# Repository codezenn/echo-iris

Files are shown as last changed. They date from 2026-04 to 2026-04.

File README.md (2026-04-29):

# Echo IRIS

A voice interactive AI agent on a mini-Jeep platform. Built for ECE 202 at
Colorado State University, Spring 2026. This is the end-of-semester archive
of the Group 35 deliverable.

**Status.** v1.0.0 released April 22, 2026. Demo day shipped in Room C105/107.
This repository is the permanent home for the codebase, hardware
documentation, 3D models, and setup guides. Future ECE 202 teams are
encouraged to fork, extend, and pick up where Group 35 left off.

## What IRIS Stands For

Intelligent Raspberry-Pi Imaging System.

| Letter | Meaning |
|---|---|
| I | Intelligent  |
| R | Raspberry Pi |
| I | Imaging |
| S | System |

## What It Does

Walk up to the Jeep, say "hello IRIS," and ask a question. IRIS hears you
through a wireless lavalier mic, recognizes your speech locally with Vosk,
checks your question against a fast path keyword dictionary for common demo
questions, and either responds instantly or hands the question to a local
qwen3.5:2b language model running through Ollama. Piper text to speech
voices the answer through a USB sound card. Throughout the entire session,
a Sony IMX500 AI camera runs YOLO11n object detection on its on-camera
neural processor and shows visitors a live preview window with bounding
boxes drawn over themselves and surrounding objects. Ask "what do you see"
and IRIS uses the qwen3.5:2b vision model to describe the scene in spoken
English. Switch personalities by saying "switch to pirate mode" or "go
playful." Everything runs locally on the Pi with no cloud dependency.



## Team

| Member | Role |
|---|---|
| Marc S. | Project lead. AI agent, voice pipeline, software |
| Giovanni G. | 3D design and printing. Speaker mount, Pi enclosure |
| Obaid A. | Hardware. Jeep assembly, wiring, GPIO, power |

## Key Features

Wake word listening with conversation mode. After IRIS responds, the agent
stays in listening mode for 12 seconds so visitors can ask follow up
questions without resaying the wake word.

Local speech recognition via Vosk at 48 kHz. No internet required.

Local language model. qwen3.5:2b runs through Ollama on the Pi. The system
prompt and DEMO_ANSWERS keyword fast path handle approximately 80 percent
of expected demo day questions in under 100 milliseconds. The LLM handles
everything else.

Concurrent live object detection. YOLO11n runs continuously on the Sony
IMX500 on camera neural processor at zero Pi CPU cost. Visitors see
themselves highlighted with bounding boxes throughout the conversation.

On demand LLM vision. Ask "what do you see" and the qwen3.5:2b vision model
captures a frame and describes the scene in spoken English.

Three personality modes. Professional, playful, and pirate. Switch by voice
command at any time.

Conversation scoreboard. IRIS counts how many people it has talked to and
will tell you the count when asked.

Easter eggs. A few hidden surprises for the curious. Try asking what grade
the project deserves.

Chat memory. Conversation history persists across turns within a session
and is logged to disk for review.

Live status indicators. Discrete LEDs driven by an Arduino Nano R4 over
serial show wake/listen/think/speak/error states.

## Architecture at a Glance

```
arecord (48 kHz) -> Vosk -> [easter eggs / personality switch / scoreboard
                            / vision trigger / DEMO_ANSWERS / LLM]
                         -> Piper TTS -> pygame.mixer -> USB speaker

Sony IMX500 NPU -> YOLO11n -> Picamera2 -> live preview window (concurrent)

Voice trigger ("what do you see") -> rpicam-still -> qwen3.5:2b vision -> spoken response
```

For the full architecture writeup, see [docs/architecture.md](docs/architecture.md).

## Hardware Highlights

The full bill of materials with funding sources and unit costs lives in
[hardware/BOM.md](hardware/BOM.md). The headline components are below.

| Component | Notes |
|---|---|
| Raspberry Pi 5 (16GB) | Production board, NVMe boot |
| Sony IMX500 AI Camera | Runs YOLO11n on-camera at zero Pi CPU cost |
| Wireless K1 Lavalier Mic | 48 kHz USB Composite Device |
| Waveshare USB Sound Card | Speaker output, USB PnP Device |
| Arduino Nano R4 | LED status indicators, pan/tilt servos via PWM |
| UPS HAT B | Backup power, pogo pin connection (GPIO free)  |
| 512GB NVMe via M.2 HAT+  | Boot drive, primary storage |
| XGRAVITY Mini-Jeep | Cars4Kids "Gravity" platform, white variant |

For the chassis specifications and the spec source URL, see
[hardware/platform_specs.md](hardware/platform_specs.md).

## Software Stack

| Component | Tool |
|---|---|
| Speech recognition | Vosk (small English model, offline) |
| Language model | qwen3.5:2b via Ollama |
| Text to speech | Piper, en_GB-vctk-medium voice |
| Object detection | YOLO11n on Sony IMX500 NPU |
| Vision (on demand) | qwen3.5:2b vision via Ollama |
| Camera interface | Picamera2, rpicam-still |
| Audio playback | pygame.mixer |
| Microcontroller | Arduino Nano R4 (Renesas RA4M1) |
| Operating system | Raspberry Pi OS Bookworm 64-bit |
| Language | Python 3 |

For full upstream license information including the AGPL-3.0 implication
that flows from YOLO11, see [ATTRIBUTIONS.md](ATTRIBUTIONS.md).

## Two Build Paths

Echo IRIS supports two hardware targets with two separate scripts.

**8GB Pi build** (`echo_iris_8gb.py`). The original development Pi.
DEMO_MODE keyword only path with no LLM at runtime, used for fallback and
crash proof demonstrations. Setup steps in
[docs/setup_guide_8gb.md](docs/setup_guide_8gb.md).

**16GB Pi build** (`echo_iris_16gb.py`). The production demo day script.
Full multi module architecture with LLM, vision, personalities, scoreboard,
and easter eggs. Setup steps in
[docs/setup_guide_16gb.md](docs/setup_guide_16gb.md).

## Repository Structure

```
echo-iris/
├── software/
│   ├── echo_iris_8gb.py        # 8GB Pi entry point (DEMO_MODE keyword path)
│   ├── echo_iris_16gb.py       # 16GB Pi entry point (production)
│   ├── iris_detector.py        # IMX500 + YOLO11n live detection
│   ├── iris_monitor.py         # UPS and system monitor
│   ├── iris_rag.py             # Optional retrieval pipeline (runtime-disabled)
│   ├── iris_knowledge.md       # 26-chunk RAG knowledge base
│   ├── sound_manager.py        # Sound effects via pygame.mixer
│   ├── scoreboard.py           # Conversation counter
│   ├── personality_manager.py  # Professional / playful / pirate
│   ├── personalities.json      # Personality definitions
│   ├── chat_memory.py          # 16-turn sliding-window history
│   ├── easter_eggs.py          # Hidden interactions
│   ├── run.sh                  # Auto-restart wrapper
│   ├── requirements.txt        # Pinned Python dependencies
│   └── README.md               # Module index
├── hardware/
│   ├── BOM.md                  # Full bill of materials
│   ├── platform_specs.md       # Cars4Kids Gravity chassis
│   ├── wiring_diagrams/
│   └── assembly_photos/
├── 3d-models/
│   ├── prototypes/
│   ├── speaker_case_final.stl
│   ├── pi_enclosure.stl
│   ├── led_housing.stl
│   ├── camera_klammer.stl
│   ├── nano_clip.stl
│   └── README.md               # Print settings
├── docs/
│   ├── architecture.md
│   ├── demo_day_script.md
│   ├── setup_guide_8gb.md
│   ├── setup_guide_16gb.md
│   └── troubleshooting.md
├── README.md
├── LICENSE
├── ATTRIBUTIONS.md
├── CHANGELOG.md
├── CONTRIBUTING.md
└── .gitignore
```

## Getting Started

For a complete from scratch setup on a fresh Raspberry Pi, follow the setup
guide that matches your build target. The 8GB guide is the simpler path and
covers the demo mode only configuration. The 16GB guide covers the full
production stack including Ollama, the qwen3.5:2b model pull, the IMX500
firmware setup, the audio device verification routine, and the Arduino LED
bridge flashing.

[docs/setup_guide_8gb.md](docs/setup_guide_8gb.md)

[docs/setup_guide_16gb.md](docs/setup_guide_16gb.md)

## Quick Start (already configured)

```
cd ~/echo-iris/software
./run.sh
```

The `run.sh` wrapper auto restarts the agent after Ctrl+C. To run the
script directly without auto restart, use `python3 echo_iris_16gb.py` for
the production build or `python3 echo_iris_8gb.py` for the 8GB build.

IRIS will play a startup sound, speak a greeting, and begin listening for
its wake word.

## Documentation

[CHANGELOG.md](CHANGELOG.md). Full version history, what shipped, what was
deferred, and known issues.

[ATTRIBUTIONS.md](ATTRIBUTIONS.md). Upstream open source dependencies and
their licenses, including the AGPL 3.0 interaction from YOLO11.

[docs/architecture.md](docs/architecture.md). System architecture, module
walkthrough, design decisions, and future work invitations.

[docs/troubleshooting.md](docs/troubleshooting.md). Audio routing, vision
recovery, LLM latency, undervoltage diagnosis, Arduino cable traps.

[docs/demo_day_script.md](docs/demo_day_script.md). The actual moments from
demo day, including what failed and what saved the run.

[CONTRIBUTING.md](CONTRIBUTING.md). Guidance for future ECE 202 teams,
open source forkers, and anyone extending the codebase.

## Sister Project

A green Jeep variant runs voice-controlled motor drive on a separate 16GB
Pi using two Cytron MDD10A motor drivers. That code lives in a sibling
repository maintained by the green Jeep team.

## Future Development

This repository is designed to outlive the semester. Future teams might
take on any of the following.

Voice-announced YOLO detections. The detection runs continuously today but
IRIS does not narrate what it sees unless asked. Adding a "narration mode"
that periodically speaks new detections would close the loop.

V2V communication. The original proposal called for MQTT-based message
passing between the white IRIS Jeep and the green Jeep. Architecture is
documented but not built.

Autonomous driving. The combination of YOLO11n object detection, the
existing motor driver pattern from the green Jeep, and the voice control
layer is the foundation for an autonomous lane following or
obstacle avoidance demo.

Faster LLM. The current qwen3.5:2b takes 28 to 41 seconds for free form
questions. A text only model swap (gemma3:1b was researched but not
benchmarked) is the most likely speed improvement.

WS2812B addressable LED strip. The original plan called for an addressable
strip, which failed during installation the day before demo and was
replaced with discrete LEDs. Returning to addressable LEDs is straightforward.

RAG reenable. The `iris_rag.py` module is shipped but disabled at runtime
because of ChromaDB ARM64 import issues on Python 3.13. A future Python
version or a different vector store would unblock it.

Real time split screen display. A planned Pygame UI for the KYY 15.6 inch
monitor with scrolling conversation panel and live camera feed was not
built.

Pirate voice. Pirate mode currently uses the same Piper speaker as
professional and playful. A separate gravelly voice would land the bit.

Streaming Ollama cancel. Mid response interrupt would let visitors stop
IRIS when answers run long.

For the complete deferred work list, see [CHANGELOG.md](CHANGELOG.md).

## License

Echo IRIS source code is released under the MIT License. See [LICENSE](LICENSE)
for the full text.

One runtime dependency (Ultralytics YOLO11) is released under AGPL-3.0,
which has implications for downstream redistribution. See
[ATTRIBUTIONS.md](ATTRIBUTIONS.md) for the full explanation. Future ECE 202
teams and downstream forkers should read the attributions before
incorporating Echo IRIS into a proprietary product.

## Acknowledgments

Professor Olivera, ECE 202, Colorado State University. Steve Henry,
Engineer in Residence. Arjunbabu Vasantharaj, ECE 202 TA. Jackie at the
ECE department for purchasing coordination. The CSU Engineering I2P Lab
for 3D printer access. The green Jeep team for the cross collaboration on
voice controlled motor drive. The open source projects that made this
possible: Ollama, Vosk, Piper, Ultralytics, the Raspberry Pi Foundation,
and Sony for the IMX500.

ECE 202 | Colorado State University | Spring 2026

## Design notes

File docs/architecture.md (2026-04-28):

# Architecture

This document describes how Echo IRIS is built as a software system. It
covers the two hardware targets, the module layout, how a single voice
interaction flows through the code, and the design decisions behind the
choices that shape the runtime. It is written for future ECE 202 teams
who will inherit and extend this codebase, with secondary value for open
source forkers and the CSU department.

## Two builds, one repository

The repository ships two distinct entry points that share helper
modules. The split exists because demo day required a guaranteed
crash-proof fallback path that the 16GB production build could not
provide on its own.

`echo_iris_8gb.py` is the demo-mode build. `DEMO_MODE = True` is set as
a module constant. No LLM runs at runtime. Every user query routes to a
keyword-indexed dictionary called `DEMO_ANSWERS` or to one of the
fallback redirect phrases. The build is intentionally simple and was
built to run on the original 8GB Pi 5 with the small Vosk model and
Piper TTS as the only AI dependencies. It exists because Ollama plus
Vosk plus Piper plus a 2B-parameter model exceeded 8GB of RAM under
load.

`echo_iris_16gb.py` is the production build. It loads the full
multi-module architecture: personality switching, scoreboard tracking,
easter eggs, persistent chat memory, the optional RAG module (disabled
at runtime by default in v1.0.0), the IMX500-backed triggered-vision
path, and the Arduino LED bridge. It was built for a 16GB Pi 5 that
shipped via the department mid-semester and ran the demo as the primary
path.

A single conversation interaction looks the same from the outside on
either build. Wake word, then a question, then a response. The
difference lives entirely behind `handle_input`. Future teams should
default to extending the 16GB build and only touch the 8GB build when a
guaranteed-no-LLM safety path is needed.

## System overview

```mermaid
flowchart LR
    AREC[Audio capture<br/>arecord 48 kHz to 16 kHz]
    VOSK[Vosk STT<br/>small model]
    DISP[handle_input<br/>wake + dispatch]

    PSWITCH[personality_manager]
    EASTER[easter_eggs]
    DEMOAN[DEMO_ANSWERS<br/>keyword match]
    MEM[chat_memory]
    OLL[Ollama qwen3.5:2b-q4_K_M]
    VISION[Triggered vision<br/>rpicam-still + LLM]

    YOLO[IMX500 NPU<br/>YOLO11n continuous]
    HDMI[KYY HDMI display]

    SCORE[scoreboard]
    SOUND[sound_manager<br/>sfx]
    PIPER[Piper TTS]
    MIX[pygame.mixer<br/>unified audio out]

    LEDBR[Arduino LED bridge<br/>W L T S E]

    AREC --> VOSK --> DISP
    DISP --> PSWITCH --> EASTER --> DEMOAN
    DEMOAN -- match --> SCORE
    DEMOAN -- miss, production --> MEM --> OLL
    OLL -- vision intent --> VISION
    VISION --> OLL
    SCORE --> PIPER
    PIPER --> MIX
    SOUND --> MIX
    DISP --> LEDBR

    YOLO --> HDMI
```

The diagram above shows two parallel paths through the camera. YOLO11n
runs continuously on the IMX500 on-camera neural processor at zero Pi
CPU cost and renders bounding boxes to the HDMI display through the
Picamera2 preview pipeline. The triggered-vision path through `rpicam-
still` only fires when the dispatch chain detects a vision-intent query,
captures one still, and passes it as a base64 image to qwen3.5:2b-q4_K_M for
scene description. These are independent. The continuous YOLO path
keeps running while the LLM is waiting on a vision response.

## Module walkthrough

The 16GB entry script imports helpers in the order below. Each module
owns one concern. The pattern is deliberate. A future team can read any
single file and understand its scope without holding the whole script in
working memory.

### sound_manager.py

Owns sound effect playback. Wraps `pygame.mixer.Sound` with a small
state machine that decides whether a given moment in the dispatch chain
should play a sound, and which one. The module is the reason the SDL
audio backend environment variables must be set before `import pygame`
in the main script. Misordering that import is a known v3.4 bug that
v1.0 ships fixed.

The module also gates two sound-effect categories that v3.4 disabled.
Tick-tock and muscle-car effects were tied to a "thinking duration"
threshold and triggered too often during the LLM-disabled DEMO_ANSWERS
path. The thresholds are pinned high enough in v1.0 that the effects
effectively never fire. Future teams who want them back should lower
the thresholds rather than re-add the call sites.

### scoreboard.py

Tracks two counters and exposes them on demand. The first counter is
demo-day conversation count. The second is wake-word event count. The
module is the answer to the demo question "how many people have you
talked to today" and the audience reaction to that answer was strong
enough to keep it as a permanent feature.

### personality_manager.py

Owns the four personalities defined in `personalities.json`: default,
pirate, robot, surfer. The module exposes `check_switch` which scans
recognized text for a switch trigger and returns the new personality
name. The 16GB script calls this near the top of the dispatch chain so
a personality switch does not first hit the DEMO_ANSWERS or LLM paths.

The module also handles a Vosk mishearing trap. The wireless K1 mic in
the demo room frequently hears "pirate" as "parrot." The module accepts
both as triggers for the pirate personality. Treat this as a pattern.
Future personalities should be tested against Vosk in the actual demo
environment before their trigger words are finalized.

### chat_memory.py

Persists conversation history to a JSON file on disk and reloads it on
script start. Memory is bounded by `MAX_HISTORY` and trimmed FIFO. The
module is only consulted on the 16GB build and only on the LLM path. The
DEMO_ANSWERS path does not read or write memory because its responses
are stateless by design.

### easter_eggs.py

A small intercept layer that catches a handful of demo-day catchphrases
before the dispatch chain reaches DEMO_ANSWERS. The grade-question
intercept switches Piper to a different speaker ID for a comedic voice
break. The "nine plus ten" intercept catches the recognized variants
"nine plus ten" and the Vosk mishearing "nine posts ten" and answers
twenty-one. Both fired during the actual demo and got the intended
laughs.

### iris_detector.py

Wraps the `rpicam-still` subprocess for the triggered-vision path.
Captures one image to a known temp path, base64-encodes it, and returns
the encoded string for the LLM payload. The module is intentionally not
threaded. Concurrent captures crashed the IMX500 firmware in early
testing and required full power cycle to recover. Treat the
"one capture per LLM request" constraint as a hard rule.

This module does not own the YOLO11n bounding box pipeline. That runs
in the Picamera2 preview loop and is configured in the entry script
directly through Picamera2 callbacks. The two paths share the camera
hardware but never the firmware-level capture pipeline.

### iris_rag.py and iris_knowledge.md

A 26-chunk hand-curated knowledge base plus a runtime cosine-similarity
retriever. The retriever cache lives at `~/iris_rag_cache.json` and is
explicitly excluded from version control. The module ships in v1.0.0
but is not wired into the dispatch chain by default. DEMO_ANSWERS
covered the demo questions reliably and the RAM cost of running RAG
alongside the 2B LLM was not worth the gain. Future teams who want to
re-enable RAG should follow the import chain in the file header
comment.

### Arduino LED bridge sketch

A small Arduino C++ program that listens on the Nano R4's USB serial
interface for single-character state codes and updates discrete status
LEDs accordingly. The protocol is intentionally minimal:

- `W` waiting (idle)
- `L` listening (active mic)
- `T` thinking (dispatch chain working)
- `S` speaking (Piper output in flight)
- `E` error

The protocol survived the WS2812B-to-discrete-LEDs hardware change
without modification because it never depended on the LED count or
addressing scheme. Future teams who swap LED hardware again can keep
the protocol and only rewrite the Arduino sketch.

## Data flow: a single voice interaction

The trace below follows one wake-word-then-question interaction through
the 16GB build, end to end.

1. The K1 lavalier mic on USB card 3 streams 48 kHz 16-bit mono audio
   into an `arecord` subprocess pipe. PyAudio is not used. The decision
   reasoning is in the design section below.
2. Audio crosses a Kaldi LinearResample that converts 48 kHz to the
   16 kHz Vosk expects. The resample is in-process and does not buffer.
3. Vosk consumes the resampled stream chunk by chunk and emits partial
   and final transcripts. The script polls for finals.
4. The first wake-word check fires on every final transcript. Wake words
   include the misheard variants Vosk produces in the demo room.
5. On a wake-word match, the script transmits `b'L'` to the Arduino
   serial bridge and starts an active listen window with a silence
   timer.
6. The next final transcript becomes the dispatch input. The script
   transmits `b'T'`.
7. `handle_input` runs the dispatch chain in this order: personality
   switch check, easter egg check, DEMO_ANSWERS keyword match, LLM
   path. The first hit wins.
8. On a DEMO_ANSWERS hit, the matched entry returns its answer plus
   optional contextual acknowledgment. The scoreboard increments. The
   script transmits `b'S'`.
9. On a miss in production mode, the chat history appends, an Ollama
   payload is built with the system prompt and message history, and
   the request fires against `localhost:11434`. `think: False` is set
   at the top level of the payload to disable qwen3.5's reasoning chain.
   `num_thread: 2` caps Ollama at 2 of 4 CPU cores.
10. If the LLM returns a vision-intent response, the script invokes
    `iris_detector` for one still capture, base64-encodes the image,
    and re-sends a follow-up payload with the image attached. The
    response from this second call is the text spoken to the user.
11. The response text passes through a sanitization step that strips
    asterisks, hashes, and any non-ASCII characters that would crash
    Piper or the latin-1 Pi terminal.
12. The sanitized text streams to a Piper subprocess. Piper's raw PCM
    output is captured and handed to `pygame.mixer.Sound(buffer=...)`
    rather than piped to `aplay`. The reasoning is in the design
    section.
13. After playback completes, the script transmits `b'W'` and the loop
    returns to wake-word listening.

The sound_manager module operates orthogonally. It can play sound
effects at any state transition without disrupting the main flow because
pygame.mixer manages its own audio channels independently of the Piper
playback channel.

## Design decisions

Each decision below was an active choice made against an alternative
that was tried and discarded. Future teams should re-evaluate any of
these only after reading the failure mode that motivated the choice.

### arecord subprocess instead of PyAudio

The K1 wireless lavalier mic streamed clean audio when read by an
`arecord` subprocess and produced a word-doubling artifact when read by
PyAudio with the same sample rate and frame size. The artifact was not
reproducible on the wired mic the project started with. Switching to
`arecord` eliminated the issue without further investigation. The
subprocess approach also makes the audio source explicit at the
operating system level which simplifies debugging when card numbers
swap on reboot.

### pygame.mixer.Sound for Piper playback instead of aplay pipe

The 8GB build used a Piper-to-aplay subprocess pipe. The 16GB build
introduced `sound_manager` which holds an open `pygame.mixer` instance
for sound effects. Running both `aplay` and pygame.mixer concurrently
caused intermittent ALSA contention and the speaker would drop the
first half-second of one stream when the other started. Routing Piper
output through `pygame.mixer.Sound(buffer=raw_audio)` placed all audio
on the same backend and eliminated the contention.

### Pure cosine similarity over ChromaDB for RAG

The 26-chunk knowledge base is small enough that an in-memory cosine
similarity retriever finds the top-k chunks faster than ChromaDB's
client startup time. ChromaDB also imports heavy dependencies that
extend the cold-start time on the Pi. The custom retriever is roughly
80 lines of Python and depends only on `numpy`. For a knowledge base
under a few hundred chunks the trade is favorable.

### DEMO_ANSWERS dictionary as primary dispatch path

Demo questions cluster heavily around a few topics: who built it, what
it does, how it works, what the team's major is, what CSU is, what the
LLM is, what the camera is. A keyword-indexed dictionary covers more
than 90 percent of expected demo questions in low milliseconds and with
no LLM dependency. The LLM path is reserved for unstructured questions
that fall through. The order matters: the first keyword match wins, so
keyword conflicts must be resolved by ordering more specific categories
ahead of more general ones.

### Triggered-only LLM vision instead of continuous

Continuous frame-by-frame LLM vision was prototyped early and rejected.
A 2B-parameter vision model takes seconds per frame on a Pi 5. The
audience experience degrades sharply when the vision narration lags the
visual scene by 10 seconds. The triggered model only fires on
vision-intent queries, captures one still, and provides a single
response. The continuous YOLO11n path on the IMX500 NPU handles the
real-time visual feedback role with bounding boxes drawn at camera
frame rate.

### Discrete LEDs after WS2812B failure

The original LED architecture used a WS2812B addressable strip driven
by an Arduino Nano R4 over a serial bridge. The strip itself never
worked reliably enough for demo deployment. The Arduino bridge stayed.
The five-state W/L/T/S/E protocol stayed. The strip got swapped for
discrete status LEDs wired to GPIO pins on the Nano R4. Future teams
who want to revisit the strip should keep the serial protocol and
rewrite only the Arduino sketch.

### Direct Arduino PWM after PCA9685 failure

The Arducam B0283 pan/tilt bracket ships with a PCA9685 PWM driver
mounted on a UC-751 PCB. The PCA9685 was unresponsive on both the Pi 5
I2C bus and the Nano R4 I2C bus. Diagnosis was abandoned in favor of
direct PWM from Nano R4 pins D9 and D10 to the two servos. The
direct-PWM path works and is documented in the hardware setup guides.
The PCA9685 is left on the bracket as inert hardware.

### apt-mark hold for the camera stack

On the 16GB build, `libcamera`, `rpicam-apps`, `picamera2`, and the
firmware-tools-rpi package are pinned. A Pi OS update mid-development
broke the IMX500 firmware upload path until the affected packages were
rolled back. The 16GB setup guide documents the exact apt-mark hold
list that prevents a recurrence. The 8GB build does not need the hold
list because it does not use the IMX500 firmware upload path.

## Future work

The items below were considered for v1.0.0, scoped, and deferred. They
are listed here as engineering opportunities for future ECE 202 teams,
not as project failures. The demo ran. The repo is complete as
shipped.

A native Anthropic API integration would replace the local Ollama call
on the LLM path. The trade is response quality versus offline capability
and ongoing API cost. A future team could add it as a config flag.

A swap to a smaller text-only LLM such as `gemma3:1b` could improve
latency on the LLM path at the cost of response quality. The current
qwen3.5:2b-q4_K_M chosen for vision capability already runs the text path and
swapping the text model alone is a non-trivial refactor.

An evdev-based hotkey bypass would let a presenter trigger fixed
demo answers from a remote without speaking. The dispatch chain already
exists in a callable form so the integration surface is small.

A streaming-cancel feature would let the speaker interrupt a Piper
response with the wake word. The current architecture buffers the
entire response before playback so cancellation requires a refactor of
the Piper subprocess handling.

The pirate personality voice is currently the default Piper speaker
with a personality prompt. A different Piper voice model with a more
distinct timbre would improve the personality-switch effect.

WS2812B integration could be revisited with a different strip or driver
combination. The serial protocol is reusable.

Re-enabling RAG at runtime is a one-line change in the dispatch chain
plus tuning of the `MIN_CONFIDENCE` threshold. The 26-chunk knowledge
base ships as-is and can be extended.

A split-screen Pygame UI was prototyped in mid-development that placed
the YOLO11n bounding box feed and the conversation log side by side on
the KYY monitor. The split-screen layout was deferred for demo day in
favor of the cleaner single-pane Picamera2 preview. A future team who
wants to surface the conversation log live could resurrect the
prototype.

48 kHz to 16 kHz audio downsampling for Vosk is settled in v1.0.0 and
is not future work. The Kaldi LinearResample in the audio path is
stable and measured.

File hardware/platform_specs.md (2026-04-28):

# Platform Specifications

The Echo IRIS mini-Jeep chassis is a Cars4Kids "Gravity" 12-volt children's
electric ride-on, sold in the US under the XGRAVITY brand. The white
variant is the IRIS platform. The same OEM chassis in metallic black is
the platform used by the green Jeep team for their voice-controlled motor
drive variant.

## Brand Note

The chassis ships under multiple brand names from the same OEM. XGRAVITY
is the US-market label visible on the body trim. Cars4Kids Trading is the
reseller whose product page documents the specifications.

Spec source: https://www.cars4kidstrading.com/product/electric-childrens-jeep-gravity-metallic-black-12-volts/

When sourcing replacement parts, search for both "XGRAVITY" and "Cars4Kids
Gravity" since vendor listings vary.

## Specifications

| Parameter | Value |
|---|---|
| Battery | 12V, 7Ah sealed lead-acid |
| Motors | 2 x 45W DC |
| Drive configuration | Two-wheel rear drive |
| Speed range | 3 to 6 km/h |
| Maximum load | 60 kg |
| Vehicle dimensions (L x W x H) | 126 x 78 x 79 cm |
| Charging time | 8 to 12 hours typical |
| Operating time per charge | 1 to 2 hours typical |
| Remote control | 2.4 GHz parental override |
| Tires | Hard plastic, non-pneumatic |

## Why The Onboard Battery Is Not Used For Pi Power

The original project plan considered tapping the Jeep's 12V 7Ah battery
to power the Raspberry Pi, the camera, the LEDs, and the Arduino. This
approach was abandoned for two reasons.

The 7Ah capacity is small. A Raspberry Pi 5 under load draws roughly 2A
at 5V (10W). At a generous 70 percent step-down efficiency from 12V to 5V,
the Pi alone would draw approximately 1.2A from the 12V battery. The IMX500
camera, the USB peripherals, and the Arduino add another 0.5A. That puts
the total Pi-stack draw at 1.7A, which is roughly a quarter of the
battery's 7Ah capacity per hour. With the motors also drawing from the
same battery during driving demos, the Pi would either share a degraded
voltage rail with the motor controller or starve the motors of current.

The motor controller PWM noise on the 12V rail would couple into the Pi's
power supply unless heavily filtered. The Pi 5 is sensitive to undervoltage
and brownouts (verified during early testing) and the resulting throttle
flag conditions would degrade Vosk and Ollama performance unpredictably.

The decision: power the Pi stack from a separate USB-C source (Argon PWR
GaN 27W on the desk during development, UPS HAT B with internal batteries
during demos) and leave the Jeep battery for the original drive system.
The green Jeep variant takes a different approach since their primary
demonstration is voice-controlled motor drive rather than voice
conversation.

## Modifications Made

The chassis ships as a functional ride-on toy. Echo IRIS modifies it as
follows.

The hood mounts the Pi enclosure (3D printed, see `/3d-models/`).

The lid is modified to expose the camera through a custom Arducam B0283
pan/tilt bracket. The original bracket pocket and ribbon cable slot were
designed for the IMX500 + OSOYOO 300mm cable assembly.

The dashboard area mounts the KYY 15.6 inch HDMI monitor that displays
the live camera feed with YOLO bounding boxes.

The roll bar area mounts the discrete LED strip used for status indication
(replacing the originally planned WS2812B addressable strip that failed
during installation).

The interior houses the wireless lavalier microphone receiver and the
Waveshare USB sound card.

The drive system is unmodified. The original 12V battery, motor controller,
and remote control are intact and functional. Echo IRIS does not currently
control the drive system. Future ECE 202 teams adding autonomous driving
will need to either hijack the existing motor controller or replace it
with a Pi-controlled equivalent (the green Jeep team's Cytron MDD10A
pattern is the most documented example).

## Sourcing

The XGRAVITY platform is available through Cars4Kids Trading and similar
ride-on toy vendors at the link in the Brand Note section above. List
prices have varied between approximately 200 and 400 USD over the project
period depending on color and stock. Group 35 inherited its chassis from
the previous IRIS team rather than purchasing new.

## For Replacement Parts

Common wear items if you keep the chassis in service across multiple
semesters: 12V 7Ah sealed lead-acid battery (standard, available from
multiple sources for ~25 USD), the 2.4 GHz remote, and the rear-wheel
motor brushes. The OEM motor controller does fail occasionally and is
not user-serviceable. A replacement motor controller is the most likely
single-point failure for the platform.

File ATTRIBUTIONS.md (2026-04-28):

# Attributions

Echo IRIS is built on top of open source software. This file lists every
upstream component the production system depends on at runtime, the license
under which each component is released, and a brief note on how Echo IRIS
uses it. License information was verified against upstream sources at the
time of the v1.0.0 release.

The Echo IRIS source code in this repository is released under the MIT
License (see `LICENSE`). The attributions below cover dependencies, not the
project's own code.

Important license interaction. One of the runtime dependencies (Ultralytics
YOLO11) is released under AGPL-3.0. This affects how the combined system
may be redistributed. See the YOLO11 entry in the Vision and Object Detection
section below for the full explanation. Future ECE 202 teams and downstream
forkers should read that section before incorporating Echo IRIS into a
proprietary or commercial product.

## Language Model

**Qwen 3.5 2B** (`qwen3.5:2b` in the Ollama library)

License: Apache License 2.0
Upstream: Alibaba Cloud, distributed via Ollama at https://ollama.com/library/qwen3.5
Used as: primary conversational LLM and vision-language model. Loaded via the
Ollama HTTP API at `localhost:11434/api/chat`. Multimodal model, accepts text
and image input, 256K context window.

Note for Marc to verify before commit. The repo synthesis handoff specifies
the exact model tag as `qwen3.5:2b-q4_K_M` (Q4_K_M quantization variant).
The reconstructed v3.4 source in the 16GBPipelineFixes RepoContext shows
`MODEL_NAME = "qwen3.5:2b"` (no quantization suffix, default Q8_0 at 2.7 GB).
These two values do not reconcile. Confirm against the actual file at
`~/echo-iris/software/echo_iris_16gb.py` on the Pi and update this attribution
to match. The Apache 2.0 license applies to either variant.

## Speech Recognition

**Vosk** (Python bindings for the Kaldi-based Vosk API)

License: Apache License 2.0
Upstream: Alpha Cephei Inc., https://github.com/alphacep/vosk-api
Used as: offline speech recognition. The KaldiRecognizer class is initialized
at 48000 Hz and handles 48 kHz to 16 kHz resampling internally via Kaldi
LinearResample.

**vosk-model-small-en-us-0.15** (English acoustic model, 40 MB)

License: Apache License 2.0 (per the Vosk model release page)
Upstream: https://alphacephei.com/vosk/models
Used as: the loaded recognizer model.

## Text to Speech

**Piper** (release 2023.11.14-2)

License: MIT
Upstream: rhasspy/piper, https://github.com/rhasspy/piper
Used as: neural text to speech synthesis. The Piper binary is invoked as a
subprocess and its raw 22050 Hz 16-bit signed mono PCM output is fed into a
pygame.mixer.Sound buffer for playback through the Waveshare USB sound card.

Note. The original rhasspy/piper repository is now archived. Active
development has moved to OHF-Voice/piper1-gpl, which uses the GPL licensed
espeak-ng phonemizer. Echo IRIS uses the older MIT-licensed release
2023.11.14-2 binary.

**en_GB-vctk-medium voice model** (speaker ID 2)

License: CC BY 4.0 (per the model card on the Piper voices Hugging Face
repository, which inherits from the VCTK Corpus license)
Upstream: rhasspy/piper-voices, https://huggingface.co/rhasspy/piper-voices
Used as: the British English voice model loaded by the Piper binary at
runtime.

**piper-phonemize** (transitive dependency)

License: GPL (espeak-ng)
Note. The Piper binary calls espeak-ng for phonemization. The GPL applies to
the phonemizer at runtime and does not affect the redistribution of the WAV
audio Piper produces. Echo IRIS distributes neither the Piper binary nor the
espeak-ng library, only the calling code.

## LLM Runtime

**Ollama**

License: MIT
Upstream: ollama/ollama, https://github.com/ollama/ollama
Used as: the local model server that hosts qwen3.5:2b and exposes it via
HTTP at `localhost:11434`. Installed on the Pi via Pi-Apps.

**llama.cpp / ggml** (transitive dependency, statically linked into Ollama)

License: MIT
Upstream: ggerganov/llama.cpp, distributed within the Ollama binary
Note. Ollama statically links llama.cpp. The MIT license requires
attribution of the ggml authors. This entry satisfies that requirement for
any distribution of Echo IRIS that bundles or recommends the Ollama binary.

## Embeddings (RAG, runtime-disabled)

**nomic-embed-text v1.5** (`nomic-embed-text:v1.5` in the Ollama library)

License: Apache License 2.0
Upstream: nomic-ai, https://huggingface.co/nomic-ai/nomic-embed-text-v1.5
Used as: the embedding model for the optional `iris_rag.py` retrieval
pipeline. The pipeline is intentionally disabled at runtime via a try/except
import guard for the demo-day build, but the dependency is still listed
because the module ships in `/software/`.

## Audio Plumbing

**pygame** (mixer subsystem)

License: LGPL
Upstream: https://www.pygame.org
Used as: the audio mixer that plays both Piper TTS output and SoundManager
sound effects through a single ALSA client, avoiding the device contention
that occurs when separate aplay subprocesses compete for the Waveshare card.

**ALSA / aplay / arecord** (system tools)

License: LGPL (ALSA)
Upstream: https://www.alsa-project.org
Used as: the audio capture path. `arecord` is invoked as a subprocess and
its stdout is piped directly into Vosk. The Python audio libraries
PyAudio and sounddevice were both tested and rejected because of word
doubling artifacts with the K1 wireless lavalier microphone.

## Vision and Object Detection

**Ultralytics YOLO11** (yolo11n, the nano variant)

License: GNU Affero General Public License v3.0 (AGPL-3.0)
Upstream: ultralytics/ultralytics, https://github.com/ultralytics/ultralytics
Used as: real-time object detection model. YOLO11n weights are deployed to
the Sony IMX500 on camera neural processor in Sony's RPK format. Detection
runs continuously on the camera silicon while the voice agent is active,
producing labeled bounding boxes on the live preview window so visitors can
see themselves and surrounding objects highlighted while chatting with IRIS.

License note. The Ultralytics AGPL-3.0 license is strong copyleft. Any
larger work that incorporates YOLO11 at runtime, including this project as
a whole when running, falls under AGPL-3.0 obligations: the complete
corresponding source code of the larger work must be made available under
AGPL-3.0 to anyone who uses the system, including over a network. Echo IRIS
satisfies this by virtue of being a fully public open source repository.
The Echo IRIS source code in this repository remains MIT licensed (see
`LICENSE`), but downstream forkers who combine this code with YOLO11 in
any product or service inherit the AGPL-3.0 obligation for the combined
work. Commercial deployment that does not satisfy AGPL-3.0 requires an
Ultralytics Enterprise License, available at https://www.ultralytics.com/license.

**COCO dataset** (Common Objects in Context)

License: Creative Commons Attribution 4.0 (CC BY 4.0) for the annotations,
Flickr terms for the underlying images
Upstream: https://cocodataset.org
Used as: the training dataset for the pretrained YOLO11n weights. The 80
COCO classes are what `iris_detector.py` recognizes (person, chair,
backpack, laptop, etc.).

Citation. Lin, T.-Y., Maire, M., Belongie, S., Bourdev, L., Girshick, R.,
Hays, J., Perona, P., Ramanan, D., Zitnick, C. L., and Dollar, P. (2014).
Microsoft COCO: Common Objects in Context. arXiv:1405.0312.

**Sony IMX500 on-camera neural processor**

License: hardware (no software license applies to the silicon itself).
Sony provides conversion tools and a runtime under their own terms.
Upstream: Raspberry Pi IMX500 AI Camera documentation
Used as: the substrate that runs YOLO11n inference on-camera at low latency
without consuming Pi CPU cycles. Detection results are returned to the host
over the CSI interface and consumed through the Picamera2 Python interface
in `iris_detector.py`.

**Picamera2 and libcamera**

License: BSD 2-Clause (Picamera2) and LGPL 2.1 (libcamera)
Upstream: https://github.com/raspberrypi/picamera2 and https://libcamera.org
Used as: the Python interface for the IMX500 camera. Picamera2 provides
the live preview window and surfaces the on-camera detection output to
`iris_detector.py` for natural-language formatting (including the irregular
plurals dictionary that turns "1 person, 3 person" into "one person and
three people").

**rpicam-apps** (`rpicam-still`, `rpicam-hello`)

License: BSD 2-Clause
Upstream: https://github.com/raspberrypi/rpicam-apps
Used as: still capture for the LLM-based vision queries (the qwen3.5:2b
"describe what you see" code path). `rpicam-still` replaced the deprecated
`libcamera-still` on Raspberry Pi OS Bookworm.

## Python Standard Dependencies

**requests** (Apache 2.0), **pygame** (LGPL), **vosk** (Apache 2.0).
Pinned versions are listed in `requirements.txt`.

## Microcontroller

**Arduino IDE / arduino-cli**

License: AGPL 3.0 (Arduino IDE), GPL 3.0 (arduino-cli)
Upstream: https://www.arduino.cc
Used as: development and flashing toolchain for the Arduino Nano R4 sketch
that drives the discrete LED status indicators and the pan/tilt servos via
direct PWM on pins D9 and D10.

**Arduino core for Renesas (`arduino:renesas_uno`)**

License: LGPL 2.1
Upstream: https://github.com/arduino/ArduinoCore-renesas
Used as: the board package for the Arduino Nano R4 (ABX00143) Renesas RA4M1
microcontroller.

**Servo library** (Arduino core)

License: LGPL 2.1
Used as: pan/tilt servo control on the Nano R4 after the Arducam B0283
PCA9685 controller failed I2C detection.

## Hardware Platform Acknowledgments

The mini-Jeep chassis is the Cars4Kids "Gravity" platform, sold as the
XGRAVITY in its US white-trim variant. Specifications and the spec source
URL are documented in `/hardware/platform_specs.md`. No software license
applies to the chassis. The acknowledgment is included for traceability
because future ECE 202 teams will need to know the exact platform to source
replacement parts.

## Data Sources

Sound effects in `/software/sounds/` are sourced from CC0 and freely
licensed libraries, specifically SoundBible, Freesound, and OpenGameArt.
Each file's origin is documented in the SoundManager source comments.
No copyrighted audio (movie clips, song clips, franchise sound effects) is
included. All effects were normalized with `sox` to approximately 0.10 RMS
before commit.

## Reference Projects

The architectural pattern of routing TTS through a single pygame mixer to
avoid ALSA contention with simultaneous sound effect playback is adapted
from BMO by brenpoly, https://www.youtube.com/@brenpoly The audio resampling
approach, the sound effect timing pattern, and the chat memory persistence
pattern were also informed by that project.

## Licenses Not Distributed in This Repository

The full text of each upstream license is not included in this repository.
Each component above links to its upstream project where the canonical
license text lives. Future ECE 202 teams or downstream forkers who
distribute Echo IRIS as part of a larger product should retrieve and bundle
the appropriate license texts from each upstream source per that license's
redistribution requirements.

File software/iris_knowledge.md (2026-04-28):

# Echo IRIS Knowledge Base
# Used by iris_rag.py for Retrieval-Augmented Generation
# Each section separated by --- is treated as one retrievable chunk
# Keep each chunk focused on one topic and under 300 words

---
## Project Overview
Echo IRIS is an AI-powered voice-interactive agent built on a mini-Jeep platform.
It is a functional extension of IRIS 1.0, an existing ECE 202 platform at Colorado State University
designed for real-time object detection. IRIS stands for Intelligent Raspberry-Pi Imaging System.
Echo IRIS adds a full voice interaction layer, allowing IRIS to listen for spoken prompts,
process them locally on-device, and respond audibly in real time using a custom embedded AI pipeline.
The system operates autonomously on battery power with no dependency on external servers or the internet.

---
## Team
Echo IRIS was built by three ECE 202 students at Colorado State University.
Marc Sibaja is the project lead responsible for the AI agent, voice pipeline, and software architecture.
Giovanni Guerra is responsible for 3D design and printing, including the speaker mount, Pi enclosure, and LED housing.
Obaid Almutairi is responsible for Jeep and Pi assembly, wiring, GPIO connections, and power integration.
All three are equal contributors to the project.

---
## Hardware
Echo IRIS runs on a Raspberry Pi 5 with 8 gigabytes of RAM.
The vision system uses a Sony IMX500 AI Camera with a built-in neural processor for object detection.
Storage is handled by a 256 gigabyte NVMe SSD connected via M.2 HAT+.
Power is supplied by a Baseus 65 watt power bank with 20,000 milliamp hours of capacity and Power Delivery 3.0 support.
A UPS HAT with 18650 batteries provides backup power to prevent crashes during mobile operation.
A KYY 15.6 inch portable monitor displays real-time bounding boxes and system diagnostics.
A Raspberry Pi Active Cooler manages thermal output under heavy AI workloads.
A USB microphone handles voice input for speech recognition.
The total estimated hardware cost is approximately 590 dollars.

---
## Software Stack
The entire software stack runs on Python 3.
Speech recognition is handled by Vosk using a small offline model that requires no internet connection.
Text-to-speech output uses Piper TTS with a British English voice model called en_GB-vctk-medium.
The conversational AI uses Qwen3 0.6 billion parameter model served through Ollama, running completely offline on the Pi.
Object detection runs YOLO 11 nano through the Sony IMX500 camera's built-in neural processor.
Embeddings for the RAG system use nomic-embed-text v1.5 served through Ollama.
Everything runs locally with no cloud dependency.

---
## Language Model - Qwen3 0.6b
IRIS uses the Qwen3 0.6 billion parameter model as its conversational brain.
This model was chosen because it is extremely lightweight at only 522 megabytes, making it ideal for running
on a Raspberry Pi 5 with limited CPU resources alongside Vosk and Piper simultaneously.
Qwen3 0.6b is developed by Alibaba Cloud and is fully open source under the Apache 2.0 license.
It supports thinking mode for complex reasoning and non-thinking mode for fast direct responses.
IRIS uses non-thinking mode to keep voice responses quick and natural.
The model runs through Ollama, a local model runtime that manages loading and inference on the Pi CPU.
Qwen3 0.6b was selected over larger models like Qwen3 1.7b or llama3.2 because response speed matters
more than raw intelligence for a voice agent in a live demo environment.
When the 16 gigabyte Raspberry Pi 5 arrives, the team plans to upgrade to a larger model like Qwen3.5 4b
for richer, more detailed conversations.

---
## RAG - Retrieval Augmented Generation
RAG stands for Retrieval-Augmented Generation. It is a technique that improves AI responses by first
searching a knowledge base for relevant information, then passing that information to a language model
to generate an accurate answer.
Without RAG, a language model can only answer based on what it learned during training, which may be
outdated or incomplete. With RAG, the model is given fresh, specific context at query time.
IRIS uses RAG to answer questions that are not covered by its scripted keyword answers.
When a user asks something IRIS does not have a scripted response for, the RAG system converts the
question into a numerical embedding using nomic-embed-text, searches the iris_knowledge.md file for the
most similar chunks, and feeds those chunks to Qwen3 0.6b to generate a contextual answer.
This means IRIS can answer detailed questions about its hardware, software, team, and project goals
without needing every possible question pre-programmed in advance.
The RAG system runs entirely offline on the Raspberry Pi with no internet connection required.

---
## Embeddings and nomic-embed-text
An embedding is a numerical representation of text that captures its meaning as a vector of numbers.
Similar pieces of text will have similar embeddings, which allows the RAG system to find relevant
knowledge chunks by measuring how close two embeddings are in vector space.
IRIS uses nomic-embed-text version 1.5 as its embedding model, served through Ollama.
It is only 274 megabytes, runs fast on CPU, and outperforms OpenAI text-embedding-ada-002 on benchmarks.
When IRIS starts up, it embeds all chunks in the iris_knowledge.md file and caches them to disk.
On subsequent startups the cache is loaded instantly, so there is no delay building the index.
When a user asks a question, the question is embedded and compared to all cached chunk embeddings
using cosine similarity to find the most relevant context.

---
## Ollama
Ollama is a local model runtime that makes it easy to download and run open source language models
on consumer hardware. It handles model loading, quantization, and inference through a simple API.
IRIS uses Ollama to serve two models simultaneously: nomic-embed-text for embeddings and Qwen3 0.6b
for conversation. Both run completely offline on the Raspberry Pi CPU with no internet required.
Ollama is accessed through its REST API at localhost port 11434. The IRIS Python scripts send HTTP
requests to Ollama to generate embeddings and chat responses.
Ollama automatically uses quantized GGUF model formats which compress model weights to reduce memory
usage and speed up inference on CPU hardware like the Raspberry Pi.

---
## Voice Pipeline
IRIS listens passively for a wake word such as hello or iris.
When activated, IRIS greets the user and enters a conversation loop.
User speech is transcribed by Vosk in real time on the Pi CPU.
Matched questions are answered instantly from a keyword database.
Unknown questions are answered using the RAG system which retrieves relevant knowledge and passes it to the language model.
IRIS speaks responses using Piper TTS piped through aplay to a USB speaker.
The microphone is flushed after each response to prevent audio feedback.
If no question is heard within 12 seconds, IRIS goes back to sleep.

---
## Object Detection
IRIS uses a Sony IMX500 AI Camera with an on-board neural processor.
The object detection model is YOLO 11 nano trained on the COCO dataset.
It can identify over 80 types of objects including people, cars, dogs, chairs, and stop signs.
Detection runs on the camera's built-in chip, offloading computation from the Raspberry Pi CPU.
This allows object detection and voice interaction to run simultaneously without performance conflicts.
Bounding boxes and confidence scores are displayed in real time on the KYY portable monitor.

---
## IRIS 1.0 vs Echo IRIS
IRIS 1.0 was built by a previous ECE 202 team and featured real-time object detection on a green Jeep.
Echo IRIS is IRIS 2.0, also referred to as Echo IRIS, and is mounted on a white Jeep platform.
The key upgrades in Echo IRIS are a full voice interaction layer, a custom 3D printed speaker mount,
and planned vehicle-to-vehicle communication with IRIS 1.0 via MQTT.
The long-term vision includes autonomous driving, cooperative navigation, and smart robotics research.

---
## ECE 202 and Colorado State University
ECE 202 is an Electrical and Computer Engineering course at Colorado State University in Fort Collins, Colorado.
The course involves hands-on hardware and software projects using embedded systems.
Echo IRIS was proposed as a multi-semester platform that future ECE 202 teams can build on.
The project has been pitched to the department as a platform for high school recruiting demonstrations.
The ECE department may use the GitHub repository and GitHub Pages site to showcase the project publicly.

---
## Goals and Future Development
The primary goals for Spring 2026 are voice interactivity, object detection integration,
vehicle-to-vehicle communication via MQTT, and a 3D printed speaker mount.
Future development includes YOLO-based object detection with voice announcements,
V2V communication between two IRIS vehicles, autonomous driving capabilities, and a GitHub Pages public site.
The repository is designed to outlive the semester so future teams can continue development.

---
## Demo Day
Demo day is in April 2026 as part of ECE 202 at Colorado State University.
The team plans to demonstrate real-time voice interaction, object detection, and IRIS's ability to
answer questions about the project, its hardware, and its creators.
IRIS runs in demo mode during the presentation, which uses keyword-matched answers for reliability.
The RAG system handles questions outside the scripted answers.
The goal is to win best project in the class.

---
## Power System
The mobile power system uses a Baseus 65 watt power bank as the primary source.
A UPS HAT with two 18650 lithium-ion batteries provides uninterruptible backup power.
This prevents sudden shutdowns when the Jeep is moving or the power bank is swapped.
The Raspberry Pi 5 requires a stable 5 volt 5 amp power supply to prevent CPU throttling.
Earlier testing revealed undervoltage as the root cause of all system crashes and instability.
The 96 watt Apple USB-C adapter was confirmed as sufficient for bench testing.

---
## Edge AI and Why It Matters
Edge AI means running artificial intelligence models directly on a local device instead of sending
data to a remote server or cloud. IRIS is a demonstration of edge AI because every component of its
AI pipeline runs on the Raspberry Pi with no internet connection.
The benefits of edge AI include privacy since no data leaves the device, low latency since there is
no network round trip, and reliability since the system works even without wifi.
Running AI on a Raspberry Pi is impressive because the hardware is only 80 dollars yet can handle
speech recognition, text to speech, object detection, language model inference, and vector search
all simultaneously. This shows that powerful AI does not require expensive cloud infrastructure.
Edge AI is a growing field with applications in robotics, autonomous vehicles, medical devices,
and smart home systems. Echo IRIS is a small scale demonstration of what is possible at the edge.

---
## How Speech Recognition Works
When a user speaks to IRIS, the audio is captured by a USB microphone at 16,000 samples per second.
Vosk processes the raw audio stream in real time using a pre-trained acoustic model and a language model
to convert sound into text. This process is called automatic speech recognition or ASR.
Vosk is unique because it runs entirely offline using a small 40 megabyte model optimized for edge devices.
It uses a technique called Kaldi under the hood, which is the same framework used in many enterprise
speech recognition systems. The small model trades some accuracy for speed, which is the right tradeoff
for a voice agent where response time matters more than perfect transcription.
IRIS listens continuously in a loop, reading chunks of audio and feeding them to Vosk until a full
utterance is detected. Partial results are tracked to reset the silence timer and keep the session alive
while the user is still speaking.

---
## How the Voice Sounds Natural - Piper TTS
IRIS uses Piper TTS to convert text responses into spoken audio. Piper is a neural text-to-speech engine
developed by Nabu Casa, the company behind Home Assistant. It uses a neural vocoder to generate natural
sounding speech from text, which is a major upgrade over older robotic TTS systems like Festival or eSpeak.
The voice model IRIS uses is called en_GB-vctk-medium, a British English voice trained on the VCTK dataset
which contains recordings from dozens of real speakers. Speaker number 2 was selected for IRIS because
it has a clear, professional tone suitable for a demo environment.
Piper runs as a subprocess and pipes raw audio directly to aplay, the ALSA audio player, which outputs
through the USB speaker. This approach avoids loading audio libraries into Python memory and keeps the
pipeline fast and lightweight.

---
## IRIS vs Alexa Siri and Google Assistant
The key difference between IRIS and cloud assistants like Alexa, Siri, and Google Assistant is that
IRIS runs entirely on-device with no internet connection required. Cloud assistants send your voice
to remote servers to process, which requires internet, introduces latency, and raises privacy concerns
because your voice data is stored by the company.
IRIS processes everything locally on a Raspberry Pi that costs about 80 dollars. This means it works
without wifi, responds without network delay, and never sends any data outside the device.
Cloud assistants also depend on subscription services and can be shut down by the company at any time.
IRIS is fully open source, meaning anyone can inspect, modify, or extend the code for free.
The tradeoff is that IRIS is less capable than cloud assistants on general knowledge questions, but for
a focused application like answering questions about the project it is equally effective and far more private.

---
## Hardest Parts to Build - Challenges and Lessons Learned
The most challenging part of building Echo IRIS was diagnosing system crashes that appeared random.
After extensive debugging, all crashes were traced to a single root cause: undervoltage. The Raspberry Pi 5
requires a stable 5 volt 5 amp power supply, and early testing used insufficient power adapters which
caused the CPU to throttle and the system to shut down unpredictably.
The second major challenge was audio architecture. Early versions of the script stopped and restarted
the microphone stream between responses, which caused degraded speech recognition quality. The fix was
to keep the stream running continuously and flush the buffer after each response instead.
A third challenge was model selection. Larger language models caused 100 percent CPU usage and crashed
the voice pipeline. This led to the decision to use demo mode with keyword matching as the primary answer
system and reserve the language model for RAG fallback queries only.
These challenges taught the team that on edge hardware, stability and efficiency matter more than
raw capability, and that systematic debugging always beats guessing.

---
## What is a Raspberry Pi
A Raspberry Pi is a small single-board computer about the size of a credit card. It was originally
designed as an affordable educational computer to teach programming and electronics to students.
The Raspberry Pi 5 used in IRIS costs around 80 dollars and contains a quad-core ARM processor running
at 2.4 gigahertz, up to 8 gigabytes of RAM, USB ports, GPIO pins for connecting hardware, a camera
connector, and PCIe support for fast SSD storage.
Despite its small size, the Raspberry Pi 5 is powerful enough to run a full Linux operating system,
multiple AI models simultaneously, real-time object detection, and a voice interaction pipeline.
This makes it ideal for embedded AI projects like IRIS where portability, low power consumption,
and low cost are important. The entire IRIS platform runs on battery power from a power bank,
something that would be impossible with a traditional desktop or server computer.

---
## MQTT and Vehicle to Vehicle Communication
MQTT stands for Message Queuing Telemetry Transport. It is a lightweight messaging protocol designed
for devices with limited resources that need to communicate over a network efficiently.
Echo IRIS plans to use MQTT to enable vehicle-to-vehicle communication between the white Jeep and
the original green IRIS 1.0 Jeep. This would allow the two vehicles to share information such as
what objects each one detects, their positions, and status updates in real time.
MQTT works using a publish and subscribe model. One device publishes a message to a topic and any
device subscribed to that topic receives the message instantly. This is more efficient than direct
device-to-device communication because a central broker manages the routing.
The long-term vision is for the two IRIS vehicles to cooperate on tasks, share sensor data, and
eventually coordinate autonomous navigation. This is a foundational step toward the multi-agent
robotics systems used in real-world autonomous vehicle research.

---
## Cost Breakdown
The total estimated cost of Echo IRIS is approximately 590 dollars.
The Raspberry Pi 5 with 8 gigabytes of RAM costs 80 dollars and serves as the main computing unit.
The Sony IMX500 AI Camera costs 70 dollars and handles real-time object detection on its built-in chip.
The Baseus 65 watt power bank costs 90 dollars and provides mobile battery power with Power Delivery 3.0.
The official Raspberry Pi NVMe SSD and M.2 HAT plus costs 90 dollars and provides fast storage for AI models.
The KYY 15.6 inch portable monitor costs 70 dollars and displays the object detection feed and diagnostics.
The UPS HAT costs 33 dollars and provides uninterruptible power to prevent crashes during movement.
The 18650 battery pack costs 15 dollars and powers the UPS HAT.
The Raspberry Pi Active Cooler costs 8 dollars and keeps the CPU cool under heavy AI workloads.
Shipping and taxes add approximately 33 dollars to the total.
This demonstrates that a full AI robotics platform with voice, vision, and language capabilities
can be built for under 600 dollars using consumer off-the-shelf components.

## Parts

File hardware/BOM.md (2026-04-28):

# Bill of Materials

This document lists every component used in the Echo IRIS production build
as it shipped on demo day, April 22, 2026. Components are grouped by
subsystem. The Funding column indicates how the component was acquired.

Pricing reflects the spring 2026 acquisition cost where documented in the
project budget spreadsheet. Components not on the original budget show
representative April 2026 retail prices verified at the time of repo
finalization. Where prices have wide market variance (consumer electronics
sold under multiple brands, items typically sold in multi-packs), the
representative single-unit price is shown. Items marked [TBD] reflect a
specific gap Marc plans to fill before final BOM lock.

Funding source legend:
- Department: ECE department funds, processed through Jackie's purchasing
- Personal: Out-of-pocket purchase by a team member
- Inherited: Carried over from the previous IRIS team or already in the lab

## Compute

| Component | Quantity | Funding | Unit Cost (USD) | Notes |
|---|---|---|---|---|
| Raspberry Pi 5 (16GB) | 1 | Department | $205.94 | Production board, primary system. DigiKey. |
| Raspberry Pi 5 (8GB) | 1 | Inherited  | -- | Development and DEMO_MODE fallback. |
| Raspberry Pi 5 Active Cooler | 1 | Department | $5.00 | Required for thermal stability under qwen3.5:2b load. DigiKey. |
| 256GB NVMe SSD + M.2 HAT+ bundle| 1 | Department | $90.00 | Original boot drive bundle from Canakit. The 256GB is the Samsung that later became the SD-card backup. The M.2 HAT+ is the production NVMe interface. |
| 512GB BIWIN NVMe SSD | 1 | Department | [TBD] | Separate later purchase from DigiKey to expand storage. Replaced the 256GB as production boot drive. Original purchase price not on the budget spreadsheet. |
| Argon PWR GaN 27W USB-C PD | 1 | Personal | $19.99 | Desk power supply during development. Pi 5 official equivalent. |

## Vision

| Component | Quantity | Funding | Unit Cost (USD) | Notes |
|---|---|---|---|---|
| Sony IMX500 AI Camera | 1 | Department | $70.00 | Runs YOLO11n on-camera at zero Pi CPU cost. DigiKey. |
| Arducam B0283 pan/tilt bracket | 1 | Department | $26.99 | Mechanical bracket only. Servos run via direct Nano R4 PWM after PCA9685 dead. Arducam direct or Amazon. |
| OSOYOO 300mm camera ribbon cable | 1 | Department | $8.99 | Sold only as 3-cable pack (80/150/300mm) on Amazon at this price. Equivalent single-cable at Adafruit ~$1.50. |

## Audio

| Component | Quantity | Funding | Unit Cost (USD) | Notes |
|---|---|---|---|---|
| Wireless K1 lavalier mic | 1 | Personal | $19.99 | USB Composite Device, 48 kHz capture only. K1 is a generic Amazon model designator across many sellers; lock by ASIN if reordering. |
| Waveshare USB Audio sound card  | 1 | Department | $14.99 | USB PnP Device for speaker output. Waveshare SKU 18833. |
| Speaker (3W class-D, 4 ohm) | 1 | Inherited  | $1.95 | Adafruit PID 1314 reference price. Mounted in 3D printed front-facing case. |
| USB-A to USB-C mic adapter | 1 | Personal | $5.99 | Specifically USB-A male to USB-C female (do not confuse with the inverse). |

## Microcontroller

| Component | Quantity | Funding | Unit Cost (USD) | Notes |
|---|---|---|---|---|
| Arduino Nano R4 (ABX00143) | 1 | Department | $13.30 | Renesas RA4M1, 5V native logic. Arduino direct store, with headers. |
| Data-capable USB cable | 1 | Personal | $5.99 | USB-A to USB-C, USB 2.0 data. Charge-only cables prevent device detection on /dev/ttyACM0. |

## Power

| Component | Quantity | Funding | Unit Cost (USD) | Notes |
|---|---|---|---|---|
| Waveshare UPS HAT (B) | 1 | Department | $34.00 | Pogo pin connection, leaves GPIO header free. Note: budget spreadsheet listed UPS HAT (E) but actual hardware in production is HAT (B). The (B) and (E) are different products. See note below. |
| 18650 Li-ion cells (2-pack) | 1 | Department | $14.00 | UPS HAT (B) batteries. Amazon. |
| Baseus 65W power bank | 1 | Personal | $45.00 | 20000mAh, USB-C PD 3.0. Mobile demo backup. Street price varies $33-55 depending on coupons; $45 is mid-range reference. |

## Display

| Component | Quantity | Funding | Unit Cost (USD) | Notes |
|---|---|---|---|---|
| KYY 15.6" portable HDMI monitor | 1 | Department | $66.00 | Live camera feed with YOLO bounding boxes. Amazon. |

## LED Status Indicator

| Component | Quantity | Funding | Unit Cost (USD) | Notes |
|---|---|---|---|---|
| Discrete 5mm LEDs (red, yellow, green, blue) | 4 | Inherited  | $9.00 | Sold as multi-color assortment kit (typically 100+ LEDs). Per-LED cost is negligible. Replaced WS2812B after pre-demo failure. |
| Half-size solderless breadboard | 1 | Inherited  | $5.95 | Adafruit PID 64 reference price. Generics on Amazon $1-3 each. |
| 220 ohm 1/4W resistors | 4 | Inherited  | $0.75 | Adafruit 25-pack reference. Per-resistor cost is negligible. |
| 22 AWG hookup wire (multi-color set) | 1 | Inherited  | $13.99 | TUOFENG/Plusivo 6-color kit on Amazon. |

## USB Infrastructure

| Component | Quantity | Funding | Unit Cost (USD) | Notes |
|---|---|---|---|---|
| Official Raspberry Pi USB 3 Hub | 1 | Department | $12.00 | 4-port USB 3.0 hub with captive USB-A upstream cable. Optional USB-C 5V/3A power input. |

## Platform

| Component | Quantity | Funding | Unit Cost (USD) | Notes |
|---|---|---|---|---|
| XGRAVITY mini-Jeep (white) | 1 | Inherited  | -- | Cars4Kids "Gravity" 12V chassis. See platform_specs.md. No US retail SKU. Comparable 12V single-seat ride-on Jeeps run $249-$349 from US retailers (MagicCars, Walmart, Costway). |

## Shipping and Taxes

| Item | Cost (USD)  | Notes |
|---|---|---|
| Anticipated Shipping + Taxes | $38.00 | Per original department budget. Covers all spreadsheet items above. |

## Abandoned Components

These components were ordered and tested but did not ship in the final
build. They are listed here for accounting transparency and to spare
future ECE 202 teams from making the same purchases.

| Component | Quantity | Funding | Unit Cost (USD) | Why Abandoned |
|---|---|---|---|---|
| WS2812B addressable LED strip (5V, 60 LED/m, 1m) | 1 | Department | $14.95 | Failed during installation the day before demo. Replaced with discrete LEDs on breadboard. |
| Arducam B0283 PCA9685 servo controller | (included with B0283) | Department | -- | Failed I2C detection on both Pi I2C buses and on Nano R4 I2C bus. Servos run via direct Nano R4 PWM on D9/D10 instead. |
| 74AHCT125 level shifter | 1 | Personal | $1.50 | Removed from BOM after Nano R4 confirmed 5V native. Not needed. |

## Cross-Collaboration (Green Jeep)

The green Jeep team uses a separate parts list for their voice-controlled
motor drive variant. The components below are theirs, not Group 35's, and
are listed only for reference since the two builds share infrastructure.

| Component | Quantity | Approx Cost (USD) | Notes |
|---|---|---|---|
| Raspberry Pi 5 (16GB) | 1 | $205.94 | Separate Pi from IRIS production. |
| Cytron MDD10A motor driver | 2 | $29.90 each | Drives the Jeep motors via voice command. Cytron direct. |
| Sony IMX500 AI Camera | 1 | $70.00 | Same model as IRIS. |

## Cost Summary

### Department-funded (production IRIS build)

| Category | Subtotal (USD) |
|---|---|
| Compute | $300.94 |
| Vision | $105.98 |
| Audio | $14.99 |
| Microcontroller | $13.30 |
| Power | $48.00 |
| Display | $66.00 |
| USB Infrastructure | $12.00 |
| Shipping + Taxes | $38.00 |
| Abandoned (WS2812B strip) | $14.95 |
| Department subtotal | $614.16 |
| 512GB BIWIN NVMe | [TBD] |

### Personally-funded (out of pocket by team members)

| Category | Subtotal (USD) |
|---|---|
| Compute (Argon PWR) | $19.99 |
| Audio (mic, USB adapter)  | $25.98 |
| Microcontroller (cable) | $5.99 |
| Power (Baseus power bank) | $45.00 |
| Abandoned (74AHCT125) | $1.50 |
| Personal subtotal | $98.46 |

### Inherited (no acquisition cost this semester)

Raspberry Pi 5 (8GB), speaker, LEDs and breadboard parts, XGRAVITY chassis.
Reference replacement cost approximately $30-40 for the small parts plus
$249-$349 if a comparable chassis needed to be sourced new.

### Project Total

Department plus Personal totals approximately $712.62 plus the 512GB BIWIN
NVMe drive cost. The original department budget approved at $522.94
covered the seven items on the original spreadsheet plus shipping and
taxes. Actual department spending exceeded that figure once the Arducam
B0283, OSOYOO cable, Waveshare USB Audio, Arduino Nano R4, Pi USB Hub,
and WS2812B strip were added during development. The 512GB BIWIN was a
separate later purchase whose price should be added to this total.

## Notes on the UPS HAT (B) vs (E) Discrepancy

The original budget spreadsheet listed "UPS HAT (E)" at $34, but the
hardware that actually shipped on demo day is UPS HAT (B). These are
different Waveshare products and they are not interchangeable.

UPS HAT (B). Waveshare SKU 20567. Pogo pin connection. 5V/5A output.
Charges from an 8.4V barrel jack. Uses 2 x 18650 Li-ion cells. April 2026
US price approximately $30. This is what shipped.

UPS HAT (E). Newer Waveshare SKU. Pogo pin connection. 5V/6A output.
Charges over USB-C PD up to 40W bidirectional. Uses 4 x 21700 Li-ion
cells. April 2026 US price approximately $45-55.

The $34 paid figure on the spreadsheet is closer to UPS HAT (B) pricing
than to (E) pricing. Most likely the original budget mislabeled the
model number, or substitution happened during purchasing. For the BOM
of record, the deployed hardware is UPS HAT (B) and the cost figure
remains $34 as paid.

## Notes for Future Teams

The Sony IMX500 is the single highest-value Department component in the
build. It is also the most fragile from a software standpoint. Budget
time for IMX500 firmware setup and the Picamera2 quirks documented in
docs/troubleshooting.md.

The wireless K1 lavalier mic was personal hardware acquired specifically
for this project. A wired lavalier or USB conference mic would work fine
and be cheaper. The "K1" model designator is shared across many no-brand
Amazon sellers, so quality varies. Lock by ASIN if your team reorders.

The KYY portable monitor is convenient but not strictly necessary for a
demo if you can mount a small HDMI screen permanently in the Jeep.

The Argon PWR GaN 27W is overkill for the Pi 5 alone but provides
headroom for USB peripherals and prevents undervoltage warnings during
startup. The official Raspberry Pi 27W USB-C supply works equally well
at slightly lower cost.

UPS HAT (B) is the project-correct variant for two reasons: pogo pin
connection leaves the GPIO header free, and 5V/5A is sufficient for the
Pi 5 plus IMX500 plus Arduino plus USB peripherals. UPS HAT (E) adds
USB-C PD charging and 5V/6A output for $15-20 more, useful if your team
expects higher current draw or wants USB-C charging convenience. The C
and D variants block GPIO and conflict with other HATs.

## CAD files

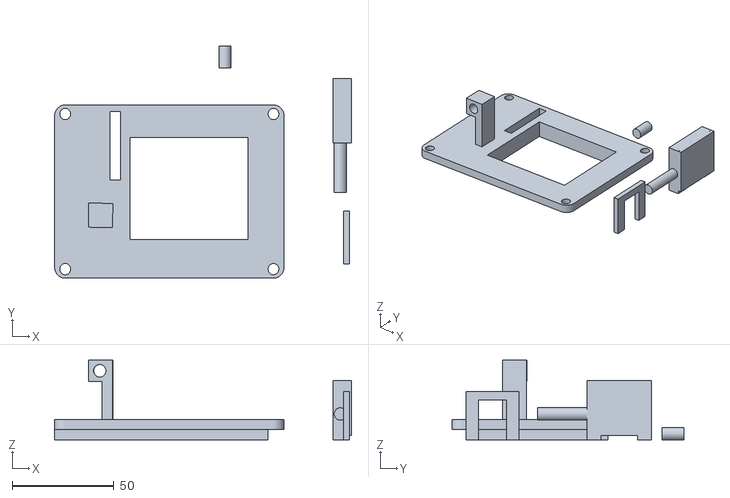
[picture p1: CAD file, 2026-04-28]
3d-models/IRIS_Lid_Cover.stl
145.6 x 114.0 x 39.0

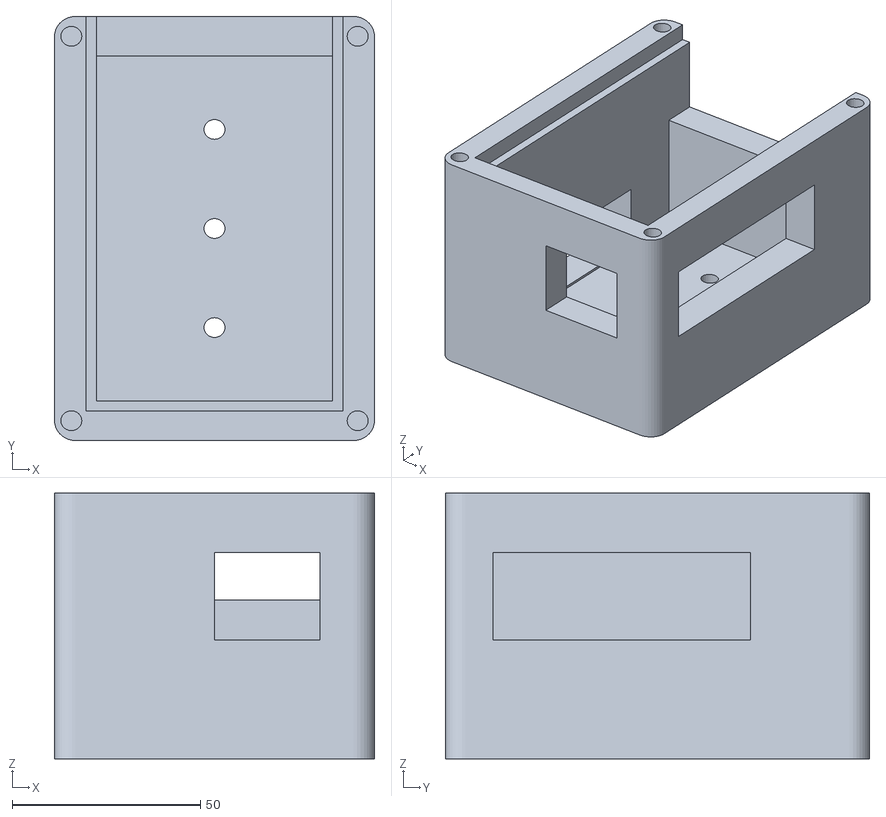
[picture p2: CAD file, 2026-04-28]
3d-models/IRIS_Cage_Base.stl
85.0 x 112.6 x 70.5

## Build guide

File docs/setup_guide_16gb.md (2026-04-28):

# Setup Guide: 16GB Production Build

This guide walks a future ECE 202 team through a full from-scratch
build of the Echo IRIS 16GB production path on a Raspberry Pi 5 (16GB).

The 16GB build is the full system: voice agent, persistent chat
memory, personality switching, scoreboard, easter eggs, runtime LLM
through Ollama, triggered LLM vision through the Sony IMX500, the
optional RAG module, and the Arduino LED bridge for status indication.

If you only need the demo path with no LLM, build the 8GB target
first using `setup_guide_8gb.md`. The 16GB build extends that
foundation rather than replacing it.

## Prerequisites

Hardware:

- Raspberry Pi 5, 16GB RAM
- NVMe SSD (256 GB or larger) on an M.2 HAT+ board. The boot from
  microSD path works but is not the production configuration.
- Pi 5 active cooler
- USB-C power supply rated 5V at 5A or better. The Argon PWR GaN 27W
  is tested working. Refer to `troubleshooting.md` before substituting.
- Sony IMX500 AI Camera, with a 300mm OSOYOO ribbon cable for routing
  to the camera bracket
- Arducam B0283 pan/tilt bracket. The on-bracket PCA9685 PWM driver is
  inert in the production build. The two servos run on direct PWM
  from Arduino Nano R4 pins D9 (pan) and D10 (tilt).
- Waveshare USB TO AUDIO sound card for speaker output
- K1 wireless lavalier mic, or equivalent USB Audio Class mic at 48 kHz
- Speaker, 3.5 mm input
- Arduino Nano R4 connected by a data-capable USB cable (charge-only
  cables will not enumerate the device)
- UPS HAT (B), pogo pin connection at I2C address `0x42`. Power for
  servos and LED hardware comes from the UPS HAT USB output.
- KYY 15.6 inch 1080p HDMI display
- Discrete status LEDs wired to Nano R4 GPIO

Software you will install:

- Raspberry Pi OS 64-bit Bookworm
- Vosk small English model
- Piper TTS with the en_GB-vctk-medium voice
- Ollama with `qwen3.5:2b-q4_K_M`, `qwen3:0.6b`, and `nomic-embed-text:v1.5`
- Picamera2, libcamera, rpicam-apps, plus IMX500 firmware tools
- arduino-cli with the Renesas UNO board package

Time required: roughly four hours of active work, plus model
downloads. The Ollama model pulls take the longest.

## Step 1: Install Raspberry Pi OS to NVMe

Use the Raspberry Pi Imager. Select `Raspberry Pi OS (64-bit)` based
on Bookworm. Image directly to the NVMe drive. Configure hostname,
username, and Wi-Fi during the imager's pre-write configuration step.
The reference deployment uses hostname `raspberrypi` and username
`penrose`.

Confirm the Pi boots from NVMe and not from microSD. The boot order
priority should be NVMe first. If the Pi boots from microSD with the
NVMe attached, run `sudo raspi-config`, navigate to Advanced Options,
Boot Order, and select NVMe.

After first boot, update:

```
sudo apt update
sudo apt full-upgrade -y
sudo reboot
```

## Step 2: Verify the power supply

Confirm no throttling before installing anything else:

```
vcgencmd get_throttled
```

Expected: `throttled=0x0`. Any other value indicates undervoltage.
Resolve power before continuing. See `troubleshooting.md` for the
throttle flag reference table.

Enable persistent journaling:

```
sudo mkdir -p /var/log/journal
sudo systemctl restart systemd-journald
```

## Step 3: System dependencies

```
sudo apt install -y python3-pip python3-venv git \
    alsa-utils libasound2-dev portaudio19-dev \
    ffmpeg sox libsox-fmt-all \
    libcamera-apps rpicam-apps python3-picamera2 \
    i2c-tools \
    build-essential cmake
```

`libcamera-apps` and `rpicam-apps` provide both the legacy and current
camera command names. The current names start with `rpicam-`. The old
`libcamera-` names are still present but should not be used in new
scripts on Bookworm. `python3-picamera2` is the Python binding the
production script uses for the YOLO11n preview pipeline.

`i2c-tools` provides `i2cdetect` for verifying the UPS HAT is visible
on the bus.

## Step 4: Pin the camera stack with apt-mark hold

Pi OS updates have broken the IMX500 firmware upload path mid-project
in the past. Pin the affected packages now to prevent silent breakage
on the next `apt upgrade`:

```
sudo apt-mark hold libcamera0.3 libcamera-apps rpicam-apps \
    python3-picamera2 firmware-tools-rpi
```

Verify the hold:

```
apt-mark showhold
```

The five packages should appear. To unpin in the future:

```
sudo apt-mark unhold <package>
```

Do not unpin without a clear reason. The hold is the project's
defense against the recurrence of a known upstream regression.

## Step 5: Verify the IMX500 camera

Connect the camera to the Pi 5 CSI port. The reference deployment uses
CAM/DISP 0. The 300mm ribbon cable's silver contacts face away from
the HDMI ports on the Pi 5 side. The camera-side orientation flips.

Test capture:

```
rpicam-hello --nopreview -t 2000
```

The camera should initialize, run for two seconds, and exit cleanly.
A successful first run with the IMX500 firmware loads the on-camera
RP2040. If the command hangs or fails with a firmware error, the
RP2040 is in a partially loaded state. Recovery requires a full
power cycle: unplug USB-C from the Pi, wait at least 15 seconds, and
replug. Do not use `sudo reboot`. The RP2040 needs the wait to fully
de-energize.

Once `rpicam-hello` succeeds, capture one still:

```
rpicam-still --nopreview -o /tmp/test.jpg -t 1000
```

The image should write to `/tmp/test.jpg`. Inspect it with any image
viewer.

Production rule: one image per Ollama vision request. Multi-image
requests crash the IMX500 firmware. The `iris_detector.py` module
enforces this.

## Step 6: Install Vosk and Piper

Same steps as the 8GB guide. Install Vosk:

```
pip install vosk --break-system-packages
mkdir -p ~/model
cd ~/model
wget https://alphacephei.com/vosk/models/vosk-model-small-en-us-0.15.zip
unzip vosk-model-small-en-us-0.15.zip
mv vosk-model-small-en-us-0.15/* .
rmdir vosk-model-small-en-us-0.15
rm vosk-model-small-en-us-0.15.zip
```

Install Piper:

```
mkdir -p ~/iris_voice
cd ~/iris_voice
wget https://github.com/rhasspy/piper/releases/download/2023.11.14-2/piper_linux_aarch64.tar.gz
tar -xzf piper_linux_aarch64.tar.gz
rm piper_linux_aarch64.tar.gz
wget https://huggingface.co/rhasspy/piper-voices/resolve/main/en/en_GB/vctk/medium/en_GB-vctk-medium.onnx
wget https://huggingface.co/rhasspy/piper-voices/resolve/main/en/en_GB/vctk/medium/en_GB-vctk-medium.onnx.json
```

## Step 7: Install Ollama via Pi-Apps

Pi-Apps is the recommended path on Bookworm because it handles the
ARM64 native build and systemd integration cleanly. Install Pi-Apps:

```
wget -qO- https://raw.githubusercontent.com/Botspot/pi-apps/master/install | bash
```

Launch Pi-Apps from the desktop menu. Navigate to AI Tools, select
Ollama, install. Pi-Apps installs the native ARM64 binary and
configures the systemd service.

Verify the service is running:

```
systemctl status ollama
```

Confirm the API is reachable:

```
curl http://localhost:11434/api/tags
```

The response is valid JSON listing currently loaded models. The list
will be empty until you pull models in the next step.

## Step 8: Pull Ollama models

```
ollama pull qwen3.5:2b-q4_K_M
ollama pull qwen3:0.6b
ollama pull nomic-embed-text:v1.5
```

The `qwen3.5:2b-q4_K_M` model is the primary LLM and the vision model. It is
roughly 2.7 GB. The `qwen3:0.6b` model is the lightweight fallback
used by the RAG module if RAG is later re-enabled. The `nomic-embed-
text:v1.5` model produces embeddings for the RAG knowledge base.

Verify all three are present:

```
ollama list
```

Warm the primary model so the first script run does not hit a
cold-start timeout:

```
ollama run qwen3.5:2b-q4_K_M "hello"
```

## Step 9: Configure the Ollama systemd override

The default Ollama service unloads models after a few minutes of
inactivity. The production build needs the model to stay resident.
Create a systemd override:

```
sudo systemctl edit ollama.service
```

Paste the following into the override file:

```
[Service]
Environment="OLLAMA_KEEP_ALIVE=-1"
Environment="OLLAMA_MAX_LOADED_MODELS=1"
Environment="OLLAMA_NUM_PARALLEL=1"
```

Save and exit. Reload systemd and restart Ollama:

```
sudo systemctl daemon-reload
sudo systemctl restart ollama
```

`KEEP_ALIVE=-1` keeps the model resident indefinitely.
`MAX_LOADED_MODELS=1` and `NUM_PARALLEL=1` prevent Ollama from
spawning concurrent inference workers, which would push the Pi past
its memory budget under load.

## Step 10: Install Python packages

```
pip install requests pygame numpy serial pyaudio --break-system-packages
```

`pygame` is used for sound effect playback through `pygame.mixer` and
for the unified audio output path that bypasses ALSA contention with
`aplay`. `numpy` is required by the in-process cosine similarity
retriever in `iris_rag.py`. `serial` is used for the Arduino LED
bridge.

## Step 11: Add the user to the dialout group

Required for write access to `/dev/ttyACM0` on the Arduino bridge:

```
sudo usermod -a -G dialout $USER
sudo reboot
```

After reboot, verify:

```
groups | grep dialout
```

The output should include `dialout`. Do not run the voice agent as
sudo to work around missing dialout membership. Sudo breaks the audio
pipeline.

## Step 12: Install arduino-cli and the Nano R4 board package

```
mkdir -p ~/bin
cd ~/bin
curl -fsSL https://raw.githubusercontent.com/arduino/arduino-cli/master/install.sh | sh
echo 'export PATH="$HOME/bin:$PATH"' >> ~/.bashrc
source ~/.bashrc
arduino-cli core update-index
arduino-cli core install arduino:renesas_uno
```

The Renesas UNO core covers the Nano R4. Verify the install:

```
arduino-cli board listall | grep -i nano
```

Connect the Nano R4 via a data-capable USB cable. Confirm the device
enumerates:

```
ls /dev/ttyACM*
```

You should see `/dev/ttyACM0`. If you see nothing, the USB cable is
likely a charge-only cable. Swap it.

## Step 13: Verify audio devices

List devices:

```
arecord -l
aplay -l
```

The K1 lavalier mic appears as a USB Composite Device on its own card
number. The Waveshare speaker appears as PnP Audio Device on a
different card number. Both are picked up automatically by
`find_usb_audio()` at script startup.

Card numbers swap on reboot. The script handles the swap. Verify the
detection log on first run.

Test the speaker:

```
speaker-test -D plughw:N,0 -c 2 -t wav
```

Substitute the speaker card number for `N`. Use `plughw` not `hw`
on the Waveshare. The raw `hw` device rejects mono.

## Step 14: Verify the UPS HAT

```
i2cdetect -y 1
```

The UPS HAT B should appear at address `0x42`. The Arducam PCA9685 is
inert in this build but if you are also doing a continuity test, the
PCA9685 nominal address is `0x40`. The production build does not rely
on the PCA9685 responding.

## Step 15: Clone the repository

```
cd ~
git clone https://github.com/codezenn/echo-iris.git
```

The 16GB script lives at `~/echo-iris/software/echo_iris_16gb.py`.

## Step 16: First run

```
cd ~/echo-iris/software
python3 echo_iris_16gb.py
```

Expected startup output:

- detected USB audio card numbers for mic and speaker
- loaded Vosk model
- Piper paths verified
- Ollama health check passes
- Arduino bridge connected on `/dev/ttyACM0`
- IMX500 camera initialized
- startup confirmation plays through the speaker

Test a wake word followed by a question that exercises the LLM path,
such as "what do you think about the weather". The dispatch chain
should fall through DEMO_ANSWERS, build the Ollama payload, and
return a streamed response in the 28 to 41 second range.

Test the triggered vision path with "what do you see". The capture
takes roughly 90 seconds end to end on the 16GB build.

## Pre-demo checklist

Run through this before a public demo. Card numbers can swap. Camera
firmware can lock. Models can unload despite the systemd override if
the service was restarted.

```
vcgencmd get_throttled
arecord -l
aplay -l
ls /dev/ttyACM*
i2cdetect -y 1
ollama list
rpicam-hello --nopreview -t 2000
ollama run qwen3.5:2b-q4_K_M "hello"
```

Each command should succeed. The throttle should read `0x0`. The
Ollama list should include the three models. The camera should
initialize cleanly. The model warmup should complete in under five
seconds on the second run.

If `rpicam-hello` hangs, perform the IMX500 firmware recovery
procedure. Unplug USB-C. Wait at least 15 seconds. Replug. The
camera should now initialize.

## Known issues

Picamera2 preview window placement is unreliable under Wayland. The
window opens at an arbitrary screen position and cannot reliably be
moved by code. Reposition manually after launch or accept the
placement.

Concurrent `rpicam-still` calls within a few seconds will cause one
to time out. The production code enforces one capture per LLM
request.

For a complete failure-mode reference including audio routing
recovery, the IMX500 firmware lock recovery procedure with reasoning,
the qwen3 thinking-mode infinite loop trap, and the charge-only USB
cable trap, see `troubleshooting.md`.

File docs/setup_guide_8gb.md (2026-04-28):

# Setup Guide: 8GB Build (DEMO_MODE)

This guide walks a future ECE 202 team through a full from-scratch
build of the Echo IRIS 8GB demo path on a Raspberry Pi 5 (8GB).

The 8GB build is the crash-proof fallback. It runs without an LLM. All
voice responses come from a keyword-indexed dictionary called
`DEMO_ANSWERS`. If you are setting up the production build with vision,
LLM, and the full multi-module architecture, follow `setup_guide_16gb.md`
instead.

## Prerequisites

Hardware:

- Raspberry Pi 5, 8GB RAM
- microSD card, 32GB or larger, or NVMe SSD with M.2 HAT+
- Raspberry Pi 5 active cooler
- USB-C power supply rated 5V at 5A or better. The Argon PWR GaN 27W
  is tested working. Lower-rated supplies may trigger undervoltage
  events. See `troubleshooting.md` for the full power supply test
  results.
- USB sound card for speaker output. The Waveshare USB TO AUDIO is the
  reference unit.
- USB microphone. The K1 wireless lavalier is the reference unit but
  any USB Audio Class mic will work. The K1 only operates at 48 kHz so
  the script's downsample path applies.
- Speaker, 3.5 mm input
- HDMI display and keyboard for first boot. Headless setup is possible
  but not documented here.

Software you will install:

- Raspberry Pi OS 64-bit Bookworm
- Python 3.11 (ships with Bookworm)
- Vosk small English model
- Piper TTS with the en_GB-vctk-medium voice
- A handful of Python packages

Time required: roughly 90 minutes of active work, plus model downloads.

## Step 1: Install Raspberry Pi OS

Use the official Raspberry Pi Imager from `raspberrypi.com/software`.
Select `Raspberry Pi OS (64-bit)` based on Bookworm. Configure the
hostname, username, and Wi-Fi during the imager's pre-write
configuration step. The reference deployment uses hostname
`raspberrypi` and username `penrose`. You can use anything you want.

Boot the Pi from the imaged storage. Complete the first-boot wizard
and apply pending updates:

```
sudo apt update
sudo apt full-upgrade -y
sudo reboot
```

## Step 2: Verify the power supply

Before installing anything else, confirm the Pi is not throttling:

```
vcgencmd get_throttled
```

Expected output: `throttled=0x0`. Any other value indicates undervoltage
and you should resolve power supply issues before proceeding. See
`troubleshooting.md` for the throttle flag reference table.

Enable persistent journaling so you can review crash logs across
reboots:

```
sudo mkdir -p /var/log/journal
sudo systemctl restart systemd-journald
```

## Step 3: Install system dependencies

```
sudo apt install -y python3-pip python3-venv git \
    alsa-utils libasound2-dev portaudio19-dev \
    ffmpeg sox libsox-fmt-all
```

`alsa-utils` provides `aplay` and `arecord` which the script invokes
directly. `portaudio19-dev` is required for any future PyAudio install
even though the production audio path bypasses it. `sox` is used for
sound effect normalization.

## Step 4: Install Vosk

```
pip install vosk --break-system-packages
```

`--break-system-packages` is required because Bookworm enforces PEP 668
externally managed environments by default. The flag is the
project-standard way to install into the system Python on this
deployment.

Download the small Vosk English model:

```
mkdir -p ~/model
cd ~/model
wget https://alphacephei.com/vosk/models/vosk-model-small-en-us-0.15.zip
unzip vosk-model-small-en-us-0.15.zip
mv vosk-model-small-en-us-0.15/* .
rmdir vosk-model-small-en-us-0.15
rm vosk-model-small-en-us-0.15.zip
```

The model is roughly 107 MB extracted. The script expects to find it at
`~/model/`.

Do not use the larger lgraph model on the 8GB build. It exceeded RAM
when running concurrently with Ollama in mid-development.

## Step 5: Install Piper

```
mkdir -p ~/iris_voice
cd ~/iris_voice
wget https://github.com/rhasspy/piper/releases/download/2023.11.14-2/piper_linux_aarch64.tar.gz
tar -xzf piper_linux_aarch64.tar.gz
rm piper_linux_aarch64.tar.gz
```

Download the en_GB-vctk-medium voice model:

```
cd ~/iris_voice
wget https://huggingface.co/rhasspy/piper-voices/resolve/main/en/en_GB/vctk/medium/en_GB-vctk-medium.onnx
wget https://huggingface.co/rhasspy/piper-voices/resolve/main/en/en_GB/vctk/medium/en_GB-vctk-medium.onnx.json
```

The Piper binary lives at `~/iris_voice/piper/piper`. The voice model
lives at `~/iris_voice/en_GB-vctk-medium.onnx`. The script expects both
paths.

Test Piper:

```
echo "Echo IRIS is ready" | ~/iris_voice/piper/piper \
    --model ~/iris_voice/en_GB-vctk-medium.onnx \
    --speaker 2 \
    --output_raw | aplay -r 22050 -f S16_LE -t raw
```

You should hear "Echo IRIS is ready" through the default audio output.
If you hear nothing, the speaker is on a USB device that is not the
default output and you will configure routing in step 7.

## Step 6: Install Python packages

```
pip install pyaudio requests --break-system-packages
```

The 8GB build keeps the package list intentionally minimal. Anything
beyond this is for the 16GB production build.

## Step 7: Verify audio devices

List input and output devices:

```
arecord -l
aplay -l
```

Note the card numbers for the USB mic and the USB speaker. The Pi
assigns these in enumeration order, which can change on reboot. The
script's `find_usb_audio()` function detects them at startup so you do
not need to hardcode anything. Verify that both devices appear and
are not on the same card.

If you are using the K1 lavalier mic, it appears as a USB Composite
Device. The Waveshare speaker appears as PnP Audio Device. The
production `find_usb_audio()` distinguishes between them. Earlier
versions did not and routed both streams to whichever device the OS
enumerated first.

Test the speaker explicitly:

```
speaker-test -D plughw:N,0 -c 2 -t wav
```

Substitute your speaker's card number for `N`. Use `plughw` not `hw`
on the Waveshare. The raw `hw` device rejects mono audio.

## Step 8: Clone the repository

```
cd ~
git clone https://github.com/codezenn/echo-iris.git
```

The 8GB script lives at `~/echo-iris/software/echo_iris_8gb.py`.

## Step 9: First run

```
cd ~/echo-iris/software
python3 echo_iris_8gb.py
```

Expected behavior at startup: the script prints the detected USB audio
card numbers, the loaded Vosk model, and the Piper paths. It then
plays a startup confirmation through the speaker and begins listening
for the wake word.

Wake word triggers include `hello`, `hey`, `iris`, and the Vosk
mishearing variants `aris`, `virus`, and others recorded in the
production wake word list.

Test the demo flow with a known DEMO_ANSWERS keyword such as
"who built you" or "what software do you use".

## Step 10: Optional bash alias

Add to `~/.bashrc`:

```
alias iris='cd ~/echo-iris/software && python3 echo_iris_8gb.py 2>/dev/null'
```

The `2>/dev/null` redirect suppresses harmless ALSA and JACK warnings
that PyAudio probes on startup.

Reload:

```
source ~/.bashrc
```

You can now launch the script with `iris` from any terminal.

## Pre-demo checklist

Run through this list before running a public demo. The 30 minutes
before the demo is the wrong time to find out a card number changed.

```
vcgencmd get_throttled
arecord -l
aplay -l
ls ~/model/am
ls ~/iris_voice/piper/piper
ls ~/iris_voice/en_GB-vctk-medium.onnx
```

Each command should succeed. The throttle output should read
`throttled=0x0`. The four file listings should print without a
"No such file" error.

Run the script. Listen for the startup confirmation. Speak a wake word
followed by a known DEMO_ANSWERS query. Confirm the response plays
back through the correct speaker. Reboot the Pi and run the
verification once more. Card numbers can swap.

## Known issues

The Bookworm `.desktop` launcher path is unreliable. Double-clicking a
correctly-formatted desktop file launches inconsistently under labwc.
Use the bash alias or run the script from a terminal until this is
resolved upstream.

Single common words spoken by the audience can match keywords by
accident. The production keyword list filters single-word triggers but
new keywords added to `DEMO_ANSWERS` should follow the multi-word rule.

For a complete failure-mode reference including audio routing recovery,
power supply diagnostics, and the one-camera-rule for the IMX500,
see `troubleshooting.md`.

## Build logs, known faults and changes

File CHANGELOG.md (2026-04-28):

# Changelog

All notable changes to Echo IRIS are documented in this file.

The format is based on [Keep a Changelog](https://keepachangelog.com/en/1.1.0/),
and this project adheres to [Semantic Versioning](https://semver.org/spec/v2.0.0.html).

## [1.0.0] - 2026-04-22

First public release. This is the demo-day version of Echo IRIS as it ran at
the ECE 202 final demonstration in Room C105/107 at Colorado State University.
The system is built around a Raspberry Pi 5 (16GB) inside a white XGRAVITY
mini-Jeep platform and runs a fully local voice agent with vision, scoreboard,
personality switching, easter eggs, and a multi-module Python architecture.

### Added

The voice agent script `echo_iris_16gb.py` v3.4 became the production entry
point for demo day. It auto-detects audio cards via `arecord -l` and `aplay -l`
on startup, captures audio through an `arecord` subprocess pipe at 48000 Hz,
feeds the stream to a Vosk recognizer that handles 48 kHz to 16 kHz
resampling internally via Kaldi LinearResample, dispatches recognized text
through a check chain of easter eggs, personality switches, scoreboard
triggers, vision triggers, and a `DEMO_ANSWERS` keyword fast path before
falling back to the LLM, then routes Piper TTS output through `pygame.mixer`
to avoid ALSA contention with the simultaneous sound effect player.

The supporting helper modules shipped in their final form: `sound_manager.py`
for startup, acknowledgment, easter egg, error, and reply indicator sounds
plus thinking sounds the team chose to disable by raising thresholds to 999;
`scoreboard.py` for tracking demo-day conversation counts with trigger
phrases like how many people have you talked to; `personality_manager.py`
for switching between professional, playful, and pirate modes defined in
`personalities.json`; `chat_memory.py` for sliding-window conversation
history of 16 turns persisted to disk via atomic write; `easter_eggs.py`
for hidden grade-response, nine-plus-ten, and other surprise interactions;
`iris_detector.py` for Sony IMX500 on-camera object detection with
irregular-plurals support; `iris_rag.py` for an optional retrieval pipeline
that is intentionally disabled at runtime via a try/except wrapper; and
`run.sh` as a bash wrapper that auto-restarts the agent after Ctrl+C.

Six v3.4 fixes shipped that made demo day work. The DEMO display path
gained a `wrap_print("IRIS", demo_answer)` call so visitors saw the answer
text in the terminal alongside hearing it. Greeting keywords changed from
`how are you` to `how are you doing` and `how are you today` to stop the
question how are you able to see from incorrectly matching the greeting
entry. The creators DEMO answer keyword list expanded with `who created`
and `created you`. The Ollama timeout went from 45 to 60 seconds to absorb
cold-start latency. SDL audio environment variables now set before the
pygame import so the mixer binds to the correct ALSA card. Conversation
mode reworked so the loop stays in listening state after `process_input`
returns, letting visitors ask follow-up questions without re-saying the
wake word for 12 seconds.

DEMO_ANSWERS keyword fast path covers approximately 80 to 90 percent of
expected demo-day questions in under 100 milliseconds, bypassing the LLM
entirely for the most common interactions. The eight categories at release
are who_are_you, software, ai_models, hardware, goals, creators,
capabilities, and greeting.

Live YOLO11n object detection runs concurrently with the voice agent
throughout the entire session. The Sony IMX500 AI camera executes the
YOLO11n nano model on its on-camera neural processor and returns labeled
bounding boxes to the host. `iris_detector.py` consumes those detections
through Picamera2 and presents a live preview window with boxes drawn over
the camera feed, so visitors see themselves and surrounding objects
highlighted in real time while chatting with IRIS. The detection runs at
zero Pi CPU cost since inference happens on the camera silicon. This is
distinct from the LLM-based vision path (qwen3.5:2b describing what it
sees), which is triggered only on phrases like "what do you see" and uses
`rpicam-still` for one-shot frame capture. The two vision paths are
complementary: continuous YOLO bounding boxes for visual feedback,
triggered LLM scene description for spoken responses.

A green Jeep cross-collaboration shipped a separate 16GB Pi build that adds
voice-controlled motor drive using two Cytron MDD10A motor drivers. Code
for that variant is documented in the architecture notes but lives in a
sibling repository.

### Changed

The Arducam B0283 PCA9685 servo controller failed I2C detection on both
Pi I2C buses and on the Arduino Nano R4 I2C bus during pre-demo
diagnostics. Servo control switched to direct PWM on Nano R4 pins D9 (pan)
and D10 (tilt). This is the supported control path going forward, not a
workaround.

The WS2812B addressable LED strip failed during installation the day
before demo. The team replaced it with discrete LEDs on a breadboard
driven by the Arduino over the same single-character serial protocol
(W/L/T/S/E states at 115200 baud over /dev/ttyACM0). The LED bridge
sketch on the Nano R4 was updated accordingly.

`sound_manager.py` AUDIODEV environment variable changed from `plughw:2,0`
to `plughw:3,0` to match the post-reboot card ordering observed on demo day.
The thinking sound thresholds (tick-tock at 10 seconds, muscle car at
30 seconds) were raised to 999 in the same file, effectively disabling
both sounds during LLM response wait. The acknowledgment beep alone
provides sufficient feedback that IRIS heard the question.

`personality_manager.py` gained a `parrot` alias in all four `SWITCH_PATTERNS`
regex alternatives, mapping to `pirate` inside `check_switch()` after the
`lower()` call. Vosk frequently transcribes the spoken word pirate as
parrot, and adding the alias prevents the switch from silently failing.

`easter_eggs.py` `NINE_TEN_PATTERN` regex updated to include `posts` as an
alternative to `plus`, since Vosk consistently mishears nine plus ten as
nine posts ten. The patched regex is `r"(?:nine|9)\s*(?:plus|posts|\+)\s*(?:ten|10)"`.

`MODEL_NAME` set to `qwen3.5:2b-q4_K_M` specifically. The Q4_K_M quantization
was kept for known-working stability over a researched but never-benchmarked
gemma3:1b swap.

`MIC_DEVICE` set to `hw:2,0` and `SPEAKER_OUTPUT` set to `plughw:3,0` after
the demo-day audio card swap. The K1 wireless lavalier microphone was
detected as a USB Composite Device on card 2 (capture only, 48 kHz), and
the Waveshare USB Audio speaker was detected as a USB PnP Device on card 3.
The card numbers can swap unpredictably on reboot, and the troubleshooting
guide documents the verification steps to take after every boot.

`num_ctx` reduced to 2048 and `num_predict` capped at 100 tokens. Voice
responses target 3 to 4 sentences (50 to 75 words). The cap hard-limits
LLM output regardless of system prompt instructions, holding response
time within an acceptable demo-day window.

A `sanitize()` defense-in-depth function strips non-ASCII from all LLM
and vision output before it reaches print or speak. Raspberry Pi OS
Bookworm sets the system locale to latin-1, and any em dash, smart quote,
or emoji in LLM output otherwise crashes the print loop. Sanitize is
applied inside `wrap_print`, `speak`, on the return value of
`query_ollama`, and on the return value of `capture_and_describe`.

### Removed

The legacy monolithic `echo_iris.py` v3.1 is no longer the entry point.
The 8GB build path uses `echo_iris_8gb.py` and the 16GB production build
uses `echo_iris_16gb.py`. All shared functionality has been extracted into
the helper modules listed in the Added section.

`iris_rag.py` runtime activation removed for demo day. The system prompt
plus DEMO_ANSWERS keyword coverage handled all expected questions without
needing the embedding-based retrieval pipeline. The module remains in the
repository, gated behind a try/except import guard, so future teams can
re-enable it after resolving its ChromaDB import dependency on Python 3.13
and ARM64.

The `iris_rag_cache.json` file is excluded from version control via
`.gitignore`. The cache contains 26 chunks of 768-dimensional embeddings
that should be regenerated per machine, not committed.

### Known Issues

LLM response time runs 28 to 41 seconds for 100-token capped responses on
the Pi 5. The qwen3.5:2b multimodal model generates at approximately 3.45
tokens per second and carries 1.38 GB of vision encoder overhead even on
text-only requests. DEMO_ANSWERS handles the common path, but free-form
LLM questions are slow. A text-only model swap (gemma3:1b was researched)
is the most likely speed improvement and is documented as future work in
`/docs/architecture.md`.

`rpicam-still` consecutive captures sometimes time out at 10 seconds. The
first capture in a session works reliably. Subsequent captures within the
same session occasionally fail with "Command timed out after 10 seconds."
Increasing the timeout, adding inter-capture delay, or using `--immediate`
not yet tested.

Vosk small model accuracy degrades at 3 to 6 feet from the wireless
lavalier mic. Documented mishearings include parrot for pirate, posts
for plus, owners were for what, and areas for iris. The personality
manager and easter eggs modules now include alias entries for the most
common substitutions. Demo-day mitigation is to clip the mic close to
the speaker.

Audio device card numbers can swap on reboot. The kernel enumerates USB
audio devices in unpredictable order. After every boot, the script's
MIC_DEVICE, SPEAKER_OUTPUT, and AUDIODEV (in both `echo_iris_16gb.py`
and `sound_manager.py`) need verification against `aplay -l` and
`arecord -l` output. A udev rule for persistent device naming is the
proper fix and is documented as future work.

Bookworm system locale defaults to latin-1 on the first-boot wizard.
The `sanitize()` function works around this at the application level,
but the proper fix (locale-gen and update-locale to en_US.UTF-8) was
not applied to the demo-day Pi.

`iris_rag.py` import fails on the production Pi due to ChromaDB
dependency issues on Python 3.13 / ARM64. The try/except wrapper handles
the failure gracefully, and RAG is intentionally disabled.

Mid-conversation sound effect playback can conflict with `pygame.mixer`
TTS output in rare cases. Startup sound conflict was resolved by routing
both Piper and SoundManager through a single mixer instance. Mid-conversation
remains an open edge case.

### Deferred Work

Several v3.5 checklist items did not ship to demo day. They are documented
honestly here and reframed as future-work invitations in `/docs/architecture.md`.

Claude API integration for online fallback when WiFi is available was
researched but not implemented. The dual offline/online conversation mode
remains a future improvement.

Gemma3:1b text-only model swap was researched but not benchmarked. This
is the most likely path to faster LLM response times.

Evdev keyboard hotkey for instant speech cancel was scoped but not built.
The current cancel path requires a Ctrl+C interrupt and full process
restart via `run.sh`.

Streaming Ollama cancel mid-generation was not implemented. The agent
waits for the full response before speaking. A streaming variant would
let users interrupt mid-response.

Pirate voice using a different Piper speaker ID was not implemented for
demo day. Pirate mode currently uses the same speaker 2 as professional
and playful modes, with personality coming entirely from the system prompt
and word choice.

WS2812B addressable LED strip integration was abandoned the day before
demo after the strip failed during installation. Discrete LEDs on a
breadboard driven by the Arduino were the demo-day workaround. Returning
to addressable LEDs is straightforward future work.

RAG re-enable on a future Python version where ChromaDB ARM64 wheels are
stable.

Real-time split-screen Pygame display for the KYY 15.6 inch monitor (left
panel scrolling conversation, right panel camera feed, bottom status bar)
was planned but not built.

48 kHz to 16 kHz Vosk downsampling work item is settled, not deferred.
Kaldi LinearResample inside the Vosk recognizer handles the conversion
internally when the recognizer is initialized at 48000 Hz. Listed here
only to clarify that earlier project notes calling this an outstanding
item are out of date.

[1.0.0]: https://github.com/codezenn/echo-iris/releases/tag/v1.0.0

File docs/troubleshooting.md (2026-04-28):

# Troubleshooting

This document collects the failure modes that cost us the most time
during development, the diagnosis steps we used to identify them, and
the recovery procedures that worked. It is organized by subsystem.
Future ECE 202 teams who hit any of these symptoms should be able to
recognize the failure here, run the diagnosis, and recover without
rediscovering the path.

## Audio

The audio subsystem is the most fragile part of the runtime. USB card
numbering changes between reboots, ALSA device routing differs between
device types, and the wireless lavalier mic only operates at one sample
rate. Most audio bugs trace back to one of these three.

### USB card numbers swap on reboot

Symptom: voice agent starts cleanly but the mic produces silence, or
the speaker plays into the wrong device, or both. `arecord -l` and
`aplay -l` show the same physical devices but at different card numbers
than the previous boot.

Cause: Linux assigns USB sound card numbers in enumeration order. On a
Pi 5 with multiple USB audio devices, the order is not deterministic
across reboots.

Diagnosis:

```
arecord -l
aplay -l
```

The K1 lavalier mic appears as a USB Composite Device. The Waveshare
USB sound card appears as PnP Audio Device. Either may land on any
card number from 1 upward.

Recovery: the production script calls `find_usb_audio()` at startup
which scans for both devices by name fragment and returns the current
card numbers. The function is the canonical way to handle the swap. Do
not hardcode card numbers in the script. If you must verify before a
demo, run `arecord -l` and `aplay -l` and confirm the script's
detection log matches.

### Composite versus PnP device routing

Symptom: mic is silent, or speaker output goes to the wrong device, or
the script picks one USB device for both input and output.

Cause: a single regex on "USB" in device name will match both the
Composite (mic) and PnP (speaker) devices. The original
`find_usb_audio()` did this and routed both streams to whichever device
the OS enumerated first.

Recovery: the patched `find_usb_audio()` distinguishes Composite from
PnP by name fragment and returns separate card numbers for the input
and the output. The patch ships in v1.0. If you write a new audio
detector, treat input and output as independent searches against
distinct name fragments.

### plughw versus hw on the Waveshare speaker

Symptom: speaker rejects mono S16_LE 22050 Hz audio with a format
mismatch error when invoked through `aplay -D hw:N,0`.

Cause: the Waveshare USB sound card refuses mono on the raw `hw`
device. ALSA's `plughw` plugin transparently converts mono to stereo
and the card accepts it.

Recovery: use `plughw:N,0` in the aplay command and in any sound
manager configuration. Never use `hw:N,0` on the Waveshare. The
sound_manager helper module is configured for plughw by default. The
pygame.mixer playback path on the 16GB build is independent of this
issue because it talks to ALSA at a different layer.

### K1 lavalier mic 48 kHz behavior

Symptom: the mic only reports a single supported sample rate and Vosk
expects 16 kHz audio, but the K1 will not produce it.

Cause: the K1 wireless lavalier dongle exposes 48 kHz as its only
supported rate over its USB Audio Class interface.

Recovery: capture at 48 kHz and resample in process to 16 kHz before
feeding Vosk. The production audio path uses `arecord -D hw:N,0 -f
S16_LE -r 48000 -c 1 -q` piped to a Kaldi LinearResample inside the
Vosk wrapper. The downsampling is settled in v1.0 and is not deferred
work.

### PyAudio word-doubling artifact

Symptom: Vosk transcripts contain doubled or echoed words, especially
at the start of utterances. Recognition accuracy is acceptable on the
older wired mic but degrades sharply on the K1.

Cause: PyAudio's buffering interacts poorly with the K1 dongle. The
exact root cause was not isolated. The artifact disappeared when the
audio path was switched to an `arecord` subprocess.

Recovery: do not read the K1 with PyAudio. Use the `arecord`
subprocess pattern documented in the production script. The PyAudio
import is no longer used on the audio capture path in v1.0.

## Vision

The Sony IMX500 ships with two failure modes worth knowing about. Both
are recoverable but the firmware upload lock is the more disruptive of
the two.

### IMX500 firmware upload lock

Symptom: `rpicam-hello` or any Picamera2-based script hangs on startup
with a message about firmware upload, or fails immediately with a
firmware error. The camera does not stream. Subsequent attempts produce
the same failure even after software reboot.

Cause: the IMX500 contains an RP2040 microcontroller that handles
on-camera firmware loading. Once the RP2040 is in a partially loaded
state, it does not respond to soft reset. The firmware upload pipeline
will not recover until the RP2040 is power-cycled at the hardware
level.

Recovery: full power cycle of the Pi, with at least a 15 second wait
between unplugging USB-C power and replugging it. Do not use `sudo
reboot`. Do not unplug and immediately replug. The RP2040 needs the
wait to fully de-energize. After the cold start, `rpicam-hello`
recovers. This procedure ran twice on demo day and worked both times.

### rpicam-still timeouts on consecutive captures

Symptom: the first vision-triggered capture succeeds. A second capture
within a few seconds times out or hangs.

Cause: `rpicam-still` on Bookworm does not always release the camera
cleanly between invocations when called rapidly in succession.

Recovery: enforce a minimum interval between captures in the calling
code. The triggered-vision path in `iris_detector.py` calls
`rpicam-still` once per LLM request and discards multi-image requests
to Ollama because qwen3.5 vision through Ollama only handles one image
per call anyway. Treat the one-capture-per-request rule as a hard
constraint.

### Picamera2 Wayland positioning

Symptom: the Picamera2 preview window appears at an arbitrary screen
position on launch, sometimes off-screen on the KYY HDMI monitor.

Cause: under Wayland, Picamera2's preview cannot reliably set its own
window position. X11 had a working API for this. Wayland does not.

Recovery: position the window after launch using a window manager
keybind, or accept the placement and use the YOLO11n bounding box
overlay from a fixed-position alternative if visual presentation
matters. There is no clean code-side fix on Bookworm Wayland.

### libcamera-* commands deprecated

Symptom: tutorials or older docs reference `libcamera-hello` or
`libcamera-still` and they fail with command-not-found.

Cause: Bookworm renamed the user-facing commands to `rpicam-hello` and
`rpicam-still`. The libcamera library is still in use under the hood.
The renamed commands are not aliases and the old names are gone.

Recovery: use `rpicam-hello` and `rpicam-still` everywhere. Add
`--nopreview` to production calls to suppress the preview window when
the script handles its own display.

## LLM

The LLM path is the slowest part of the production build and the place
where the model's quirks show up most visibly. The two recurring issues
are response latency and the qwen3 reasoning chain.

### qwen3 thinking mode infinite loop

Symptom: an LLM call returns a response containing a long internal
reasoning chain prefixed with text like `<think>` and the actual answer
arrives late or never. Some calls never return.

Cause: the qwen3 family supports a reasoning mode that runs an internal
chain-of-thought before the final response. The mode is on by default
in the Ollama API. The chain occasionally fails to terminate in a small
percentage of calls, blocking the response.

Recovery: set `think: False` at the top level of the Ollama API
request payload. It must be at the top level, not nested inside
`options`, and not in the prompt as a `/no_think` prefix. The prompt
prefix does not work reliably and is not the documented disable
mechanism.

The production script sets this on every call. If you add a new code
path that calls Ollama, copy the payload structure from the existing
calls.

### LLM response latency

Symptom: a complete LLM round trip takes more than 30 seconds and the
audience experience suffers visibly.

Cause: a 2B-parameter model on a Pi 5 is genuinely slow. Cold starts
add seconds. Long context inflates the per-token time.

Recovery: the production build sets `num_ctx: 2048` and
`num_predict: 100` in the Ollama options to bound the work. The Ollama
service is configured with `KEEP_ALIVE=-1`, `MAX_LOADED_MODELS=1`, and
`NUM_PARALLEL=1` via systemd override so the model stays resident. With
these settings, a typical text-only response lands at 28 to 41
seconds. A vision response lands around 90 seconds. If the response
exceeds these ranges by a wide margin, the system is likely thermally
throttling or hitting swap.

### Ollama health check

Diagnosis: confirm the service is up and the expected models are
loaded.

```
systemctl status ollama
ollama list
curl http://localhost:11434/api/tags
```

The active models list should include `qwen3.5:2b-q4_K_M`,
`nomic-embed-text:v1.5`, and `qwen3:0.6b`. If the service is up but a
model is missing, run `ollama pull <model>` to fetch it.

### Cold start exceeds timeout

Symptom: the very first LLM call after boot times out and IRIS
responds with the timeout fallback phrase. Subsequent calls succeed.

Cause: Ollama loads the model on first request unless the keep-alive
configuration is set. Loading a 2B model from disk on a Pi 5 takes more
than the script's default timeout.

Recovery: warm the model before the demo with `ollama run qwen3.5:2b-q4_K_M
"hello"`. The keep-alive override prevents unload between calls but
does not avoid the first load. The 16GB setup guide includes this in
the pre-demo checklist.

## Hardware and Power

Power problems were the single largest category of hardware failure on
the project. The throttle flag is the first place to look when the Pi
behaves erratically.

### Throttle flag interpretation

The Pi exposes its current throttle status through `vcgencmd`.

```
vcgencmd get_throttled
```

The output is a single hexadecimal value. The bits map to undervoltage,
frequency cap, throttling, and soft-temperature events, both currently
active and any-time-since-last-boot.

Reference table for values seen during this project:

```
0x0       OK. No undervoltage, no throttling.
0x1       Undervoltage currently active.
0x10000   Undervoltage occurred since boot. Now recovered.
0x50000   Undervoltage and throttling occurred since boot. Power supply
          is borderline at minimum and inadequate at peak load.
```

Treat any nonzero value as a power problem. Do not run the voice agent
under stress until the value reads `0x0` consistently across reboots
under load.

### Power supply test results

The table below summarizes units tested during the project against the
loaded Pi 5 stack: Pi, NVMe, USB hub, Waveshare audio, K1 dongle, IMX500
camera, KYY display, UPS HAT, Arduino Nano R4. Future teams testing
other units should add rows rather than replace these.

| Supply | Result | Notes |
|---|---|---|
| Anker PowerCore 3 5000 | Failed | Triggered `0x50000` under load. Removed from the project. |
| Apple 30W USB-C | Failed | Voltage held around 0.90 V at the test rail under load. Insufficient even at idle plus camera. |
| Apple 96W USB-C | Worked | Used as interim during early dev. Replaced by Argon for cost. |
| Argon PWR GaN 27W | Worked | `vcgencmd get_throttled` confirmed `0x0`. Permanent desk supply. |
| Baseus 65W power bank | Untested at scale | Theoretical mobile fit. Requires a 5 A E-Marked USB-C cable. Not stress-tested under demo conditions. |

### Diagnosing undervoltage

The kernel logs an undervoltage event with a clear message:

```
hwmon hwmon4: Undervoltage detected
hwmon hwmon4: Voltage normalised
```

The pair indicates a transient. Persistent undervoltage logs the first
without the second. Enable persistent journaling so the logs survive
the reboot you will be tempted to do mid-debug:

```
sudo mkdir -p /var/log/journal
sudo systemctl restart systemd-journald
```

### Undervoltage masquerading as a software bug

Symptom: random crashes, audio glitches, USB device disappearance, file
system errors that come and go, the voice agent freezing partway
through a response. No clean Python traceback.

Cause: when the Pi browns out under peak load, USB devices reset, ALSA
streams glitch, and processes die without consistent error messages.
The symptoms look like a software bug at every layer.

Recovery: check `vcgencmd get_throttled` first, every time, before
investigating any random crash. If the value is nonzero, treat it as
the root cause and do not start chasing the apparent symptom.

## Arduino and Servos

The bracket and LED control path went through one major rework when the
on-bracket PWM driver failed. The current state is direct PWM from the
Arduino. Future teams who try to revive the original PCA9685 path
should know what they are walking into.

### Nano R4 not detected on /dev/ttyACM0

Symptom: `ls /dev/ttyACM*` shows no device. `dmesg` shows no USB CDC
ACM enumeration. The Nano R4 LED is on but the OS does not see it.

Cause: the USB cable is a charge-only cable. Its data lines are not
connected. The Nano R4 powers up and runs but cannot enumerate.

Recovery: replace the cable with a known data-capable USB-A to
USB-C or USB-A to USB-Mini cable. This is the single most common
Arduino setup mistake on the project. Keep one labeled data-capable
cable in the kit.

### dialout group permission silent failure

Symptom: a Python `serial.Serial("/dev/ttyACM0", 115200)` call returns
a permission-denied error, or worse, a successful object that silently
discards writes. LED states never change despite the script running
without errors.

Cause: the Pi user is not in the `dialout` group. Some Python serial
implementations swallow the permission error.

Recovery:

```
sudo usermod -a -G dialout $USER
```

Reboot. Confirm with `groups | grep dialout`. Do not run the voice
agent as sudo to work around this. Sudo breaks the audio pipeline.

### PCA9685 unresponsive on the Arducam B0283

Symptom: the I2C bus shows the UPS HAT at `0x42` but no device at
`0x40`. `i2cdetect -y 1` confirms the bus is alive. The bracket arrives
assembled and the on-board PCA9685 LED is lit.

Cause: indeterminate. The PCA9685 is genuinely unresponsive on both the
Pi 5 I2C bus and the Nano R4 I2C bus. Diagnosis was not pursued past a
point of returns.

Recovery: drive the two servos directly from Nano R4 PWM pins D9 (pan)
and D10 (tilt). The shipped firmware sketch on the Nano R4 includes
the direct-PWM servo handler. The PCA9685 is left on the bracket as
inert hardware. Future teams who want to revisit it should start with a
multimeter continuity test on the Arducam UC-751 PCB before assuming
the chip itself is bad.

### Servo power routing

Critical rule: servo and LED power comes from the UPS HAT USB output.
Not from the Nano R4 5V pin.

The Nano R4 5V pin is rated for roughly 500 mA. A two-servo plus LED
load pulls multiples of that at peak. Powering the load from the Nano
will brown out the board and may cause permanent damage. The UPS HAT
USB output is sized for the load and is on the same regulated rail as
the Pi.

The data and ground lines run through the Nano. Power does not.

### never install rpi_ws281x

Even though the WS2812B strip was abandoned, the warning stands for
future teams who try to drive an LED strip from the Pi GPIO directly.
Installing `rpi_ws281x` reconfigures the Pi's PWM hardware and breaks
Piper TTS audio. The breakage is not obvious until you try to play
audio. Roll back the install if it happens.

The recommended path for any addressable LED work is to keep the
Arduino bridge and update the Arduino sketch. The Pi does not drive
LED data directly.

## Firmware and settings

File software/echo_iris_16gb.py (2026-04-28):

#!/usr/bin/env python3
"""
Echo IRIS v3.4 - 16GB Production Voice Agent
ECE 202 | Group 35 | Colorado State University | Spring 2026
Team: Marc Sibaja, Giovanni Guerra, Obaid Almutairi

Architecture:
    arecord subprocess -> Vosk (48kHz) -> Demo answer / Easter egg / Personality
    -> Ollama qwen3.5:2b-q4_K_M -> Piper TTS via pygame.mixer -> Waveshare speaker
    IMX500 AI Camera -> MobileNet SSD on-sensor -> live bounding boxes + voice summaries

Audio capture uses arecord subprocess pipe. Do NOT replace with PyAudio or sounddevice.
Both cause word-doubling artifacts with the K1 wireless mic on this Pi.

Changes from v3.1:
    - Clean demo terminal: only USER/IRIS lines shown (debug behind --debug flag)
    - ANSI colors: USER cyan, IRIS green, status yellow, errors red
    - Separator lines between conversation exchanges
    - Dynamic terminal width via shutil.get_terminal_size()
    - Ack sound plays every 3-5 questions (randomized) instead of every time
    - Status indicators: Listening / Thinking / Speaking shown during operation
    - Greeting not printed to terminal (only spoken)
    - --debug flag restores full developer output (WAKE/HEAR/DEMO/EGG/MODE etc.)

Usage:
    python3 echo_iris_16gb.py              # Demo mode (clean output, full startup)
    python3 echo_iris_16gb.py --quiet      # Dev mode (no startup sound/greeting)
    python3 echo_iris_16gb.py --debug      # Dev mode (full diagnostic output)
    python3 echo_iris_16gb.py --quiet --debug  # Both
"""

import os
import sys
import json
import subprocess
import requests
import time
import signal
import re
import textwrap
import shutil
import argparse
from iris_detector import IrisDetector
import threading
import random
from datetime import datetime

# ============================================================
#  AUTO CARD DETECTION
# ============================================================

def find_audio_devices():
    """Detect mic and speaker card numbers dynamically.
    Mic = USB Composite Device (K1 wireless lavalier)
    Speaker = USB PnP Audio Device (Waveshare)
    Returns (mic_device, speaker_device) or falls back to defaults.
    """
    mic_card = None
    speaker_card = None

    try:
        result = subprocess.run(["arecord", "-l"], capture_output=True, text=True, timeout=5)
        for line in result.stdout.splitlines():
            if "Composite" in line or "composite" in line:
                parts = line.split("card ")
                if len(parts) > 1:
                    mic_card = parts[1].split(":")[0].strip()
                    break
    except Exception as e:
        print(f"[INIT] Warning: arecord -l failed: {e}")

    try:
        result = subprocess.run(["aplay", "-l"], capture_output=True, text=True, timeout=5)
        for line in result.stdout.splitlines():
            if "PnP" in line or "pnp" in line:
                parts = line.split("card ")
                if len(parts) > 1:
                    speaker_card = parts[1].split(":")[0].strip()
                    break
    except Exception as e:
        print(f"[INIT] Warning: aplay -l failed: {e}")

    if mic_card and speaker_card:
        mic_dev = f"hw:{mic_card},0"
        spk_dev = f"plughw:{speaker_card},0"
        print(f"[INIT] Auto-detected mic: card {mic_card} ({mic_dev})")
        print(f"[INIT] Auto-detected speaker: card {speaker_card} ({spk_dev})")
        return mic_dev, spk_dev
    else:
        print("[INIT] WARNING: Could not auto-detect audio devices. Using defaults.")
        return "hw:2,0", "plughw:3,0"


# Detect audio devices before setting SDL env vars
MIC_DEVICE, SPEAKER_OUTPUT = find_audio_devices()

os.environ["SDL_AUDIODRIVER"] = "alsa"
os.environ["AUDIODEV"] = SPEAKER_OUTPUT
import pygame

os.environ["PYTHONUNBUFFERED"] = "1"

# ============================================================
#  ANSI COLOR CODES
# ============================================================

class C:
    """ANSI color codes for terminal output."""
    CYAN = "\033[96m"
    GREEN = "\033[92m"
    YELLOW = "\033[93m"
    RED = "\033[91m"
    DIM = "\033[2m"
    BOLD = "\033[1m"
    RESET = "\033[0m"


# ============================================================
#  CONFIGURATION
# ============================================================

# Audio
MIC_RATE = 48000
READ_SIZE = 16000

# Vosk
VOSK_MODEL_PATH = os.path.expanduser("~/model")

# Piper TTS
PIPER_BIN = os.path.expanduser("~/iris_voice/piper/piper")
PIPER_MODEL = os.path.expanduser("~/iris_voice/en_GB-vctk-medium.onnx")
PIPER_SPEAKER = 2

# Ollama
OLLAMA_URL = "http://localhost:11434/api/chat"
MODEL_NAME = "qwen3.5:2b-q4_K_M"
OLLAMA_TIMEOUT = 60
NUM_CTX = 2048
NUM_PREDICT = 100
MAX_HISTORY = 6

# Voice loop
WAKE_WORDS = [
    "hello", "hey", "iris", "hello iris", "hey iris",
    "hi", "high", "aris", "virus", "hi iris",
    "harris", "areas", "alice", "iras", "eris",
]
MIN_WORDS = 3
LISTEN_TIMEOUT = 8
SILENCE_TIMEOUT = 3.0

# Display
CHAT_LOG = os.path.expanduser("~/iris_chat_log.txt")

# Ack sound frequency (plays every N questions, randomized)
ACK_MIN_INTERVAL = 3
ACK_MAX_INTERVAL = 5

# Greeting (spoken only, not printed to terminal in demo mode)
GREETING = (
    "Hello! My name is IRIS, the Intelligent Raspberry-Pi Imaging System. "
    "I am a voice-interactive AI running on a Raspberry Pi inside a mini Jeep. "
    "Just say hello iris to start a conversation. "
    "What would you like to know?"
)

# Vision trigger phrases
VISION_TRIGGERS = [
    "what do you see", "what you see", "what can you see",
    "what are you seeing", "what is around",
    "look around", "describe what", "take a look",
    "take a picture", "use your camera", "use the camera",
    "do you see", "can you see", "you see anything",
    "what is in front", "who do you see", "who is there",
    "what is there", "see anything", "see right now",
    "looking at", "what is out there", "check your camera",
    "i can see", "i could see", "i see something",
    "what is that", "what are those",
]

# Friendly redirects when LLM fails
REDIRECT_PHRASES = [
    "I am not sure about that one. Try asking me about my hardware, my creators, or what I can do!",
    "That is a bit outside my expertise. Ask me about the ECE 202 project or my capabilities!",
    "Hmm, I do not have an answer for that. I know a lot about my hardware, my AI models, and what I can do though!",
]

# ============================================================
#  DEMO ANSWERS - Keyword matched, instant, no LLM needed
#  First match wins. SPECIFIC topics before GENERIC ones.
# ============================================================

DEMO_ANSWERS = [
    # ---- SPECIFIC TOPICS FIRST ----
    {
        "name": "object_detection",
        "keywords": ["object detection", "detect objects", "bounding box", "bounding boxes",
                     "mobilenet", "yolo", "neural network camera", "ai camera",
                     "imx500", "imx 500", "sensor ai", "tell me about the object",
                     "about the detection", "how does detection"],
        "answer": (
            "My Sony IMX500 AI Camera has a built-in neural processor that runs MobileNet SSD "
            "object detection directly on the image sensor. That means I can detect and classify "
            "objects at 30 frames per second with zero CPU cost on the Raspberry Pi. The bounding "
            "boxes you see on the monitor are drawn in real time. When you ask me what I see, I "
            "read those detection results out loud."
        ),
    },
    {
        "name": "voice_system",
        "keywords": ["voice system", "how do you hear", "how do you talk",
                     "speech recognition", "text to speech", "how do you listen",
                     "how do you speak", "microphone work", "voice pipeline",
                     "how do you understand"],
        "answer": (
            "My voice system has three stages. First, I listen through a wireless lavalier "
            "microphone and convert your speech to text using Vosk, an offline speech recognition "
            "engine. Then I process the text, either matching it to a known answer instantly "
            "or sending it to my AI brain for a response. Finally, I convert my reply to speech "
            "using Piper text-to-speech with a British voice and play it through my speaker. "
            "The entire pipeline runs locally with no internet."
        ),
    },
    {
        "name": "class_info",
        "keywords": ["what class", "which class", "course", "capstone",
                     "semester project", "class project"],
        "answer": (
            "I was built for ECE 202, Introduction to Electrical and Computer Engineering "
            "Projects, at Colorado State University during the Spring 2026 semester. It is a "
            "capstone-style course where teams design and build a complete engineering project. "
            "My team is Group 35."
        ),
    },
    {
        "name": "how_built",
        "keywords": ["how long", "how did you", "build process", "development",
                     "difficult", "challenge", "hard to build", "challenges",
                     "problems", "difficulties", "obstacles"],
        "answer": (
            "My team has been building me over the Spring 2026 semester. The biggest challenges "
            "were getting all the AI components to run locally on a Raspberry Pi without cloud "
            "services, resolving audio device conflicts between the microphone and speaker, and "
            "making sure I respond quickly enough for natural conversation. The team also had to "
            "work around hardware failures, including a dead servo controller board, and optimize "
            "everything for embedded hardware with limited processing power."
        ),
    },
    {
        "name": "future",
        "keywords": ["future", "next steps", "improve", "improvement", "what would you change",
                     "what's next", "upgrade", "roadmap", "after this"],
        "answer": (
            "Future improvements could include autonomous driving using the Jeep motors, "
            "a pan-and-tilt camera mount for tracking objects, faster speech recognition "
            "with Whisper, LED light patterns that react to conversation state, and a web "
            "dashboard for remote monitoring. The goal is to leave a platform that future "
            "ECE 202 students can extend with their own features."
        ),
    },
    {
        "name": "driving",
        "keywords": ["drive", "driving", "move", "moves", "does it move",
                     "can it drive", "autonomous", "self driving", "remote control",
                     "wheels", "motor"],
        "answer": (
            "The Jeep platform does not drive autonomously right now. It serves as a "
            "demonstration chassis that houses all of my electronics and gives me a fun, "
            "memorable form factor. Adding autonomous driving is a possible future extension "
            "that a future ECE 202 team could build on top of this platform."
        ),
    },
    {
        "name": "cost",
        "keywords": ["cost", "how much", "expensive", "budget", "price",
                     "money", "funding", "funded"],
        "answer": (
            "This project was department-funded through the ECE 202 course at Colorado State "
            "University. The main costs were the Raspberry Pi 5, the Sony IMX500 AI Camera, "
            "the wireless microphone, and the mini Jeep platform. The team also used personal "
            "equipment like a UPS battery HAT and NVMe SSD to keep costs within the department budget."
        ),
    },
    # ---- GENERAL TOPICS ----
    {
        "name": "who_are_you",
        "keywords": ["who are you", "your name", "what are you", "introduce yourself",
                     "about iris", "what is iris", "whats iris"],
        "answer": (
            "I am IRIS, the Intelligent Raspberry-Pi Imaging System. I am an AI-powered "
            "mini Jeep built by Marc Sibaja, Obaid Almutairi, and Giovanni Guerra for "
            "ECE 202 at Colorado State University. I can detect objects with my camera and "
            "have a conversation with you, all running on edge hardware with no internet needed."
        ),
    },
    {
        "name": "software",
        "keywords": ["software", "program", "code", "python", "how do you work",
                     "tech stack", "how does it work", "what powers you"],
        "answer": (
            "I run on Python with several AI components working together. My brain is qwen "
            "3.5 with 2 billion parameters running locally through Ollama at Q4 quantization "
            "for speed. I hear you through Vosk speech recognition and speak using Piper "
            "text-to-speech with a British voice. My Sony IMX500 AI camera runs MobileNet "
            "object detection directly on the sensor with zero CPU cost. Everything runs "
            "locally on my Raspberry Pi with no cloud or internet connection needed."
        ),
    },
    {
        "name": "ai_models",
        "keywords": ["model", "models", "ai model", "what model", "running",
                     "llama", "brain", "modeled", "motto", "module",
                     "intelligence", "smart"],
        "answer": (
            "My AI brain is qwen 3.5 with 2 billion parameters at Q4 quantization, running "
            "through Ollama at about 5 tokens per second. For speech recognition I use Vosk, "
            "and for text-to-speech I use Piper with a British voice. My Sony IMX500 AI camera "
            "runs MobileNet SSD object detection directly on the image sensor at 30 frames per "
            "second with no CPU overhead. Everything runs locally on the Raspberry Pi."
        ),
    },
    {
        "name": "hardware",
        "keywords": ["hardware", "specs", "components", "parts", "built with",
                     "made of", "raspberry", "camera", "power", "battery",
                     "jeep", "vehicle", "car"],
        "answer": (
            "I run on a Raspberry Pi 5 with 16 gigabytes of RAM and a 512 gigabyte NVMe SSD "
            "for fast storage. I see through a Sony IMX500 AI Camera with a built-in neural "
            "processor that runs object detection on the sensor itself. I hear through a wireless "
            "lavalier microphone and speak through a USB sound card. I am powered by a UPS HAT "
            "with backup batteries and have LED lights controlled by an Arduino Nano. All of "
            "this is mounted inside a white mini Jeep platform."
        ),
    },
    {
        "name": "creators",
        "keywords": ["creator", "creators", "who made", "who built", "who created",
                     "created you", "team", "marc", "obaid", "giovanni", "gio",
                     "group", "students"],
        "answer": (
            "I was built by three computer engineering students at Colorado State University. "
            "Marc Sibaja is the project lead and built my AI agent, voice pipeline, and software. "
            "Giovanni Guerra designed and 3D printed all of my custom mounts and enclosures. "
            "Obaid Almutairi handled the hardware assembly and wiring. Together they are Group 35 "
            "in ECE 202."
        ),
    },
    {
        "name": "goals",
        "keywords": ["goal", "goals", "project", "ece 202", "ece202", "purpose",
                     "why built", "why made", "semester",
                     "mission", "objective", "trying to do", "working on"],
        "answer": (
            "My creators built me for their ECE 202 capstone project at Colorado State University. "
            "The goal is to demonstrate what a small team of engineering students can build with "
            "local AI on embedded hardware. I can have voice conversations, detect objects in real "
            "time, switch personalities, and tell jokes, all running on a Raspberry Pi with no cloud "
            "needed. The bigger vision is to create a platform that future ECE students can build on."
        ),
    },
    {
        "name": "capabilities",
        "keywords": ["can you do", "capable", "abilities", "features", "what can you",
                     "demonstrate", "demo", "do you do"],
        "answer": (
            "I can have a voice conversation with you about almost anything. I can detect and "
            "identify objects in real time through my AI camera. I can switch between three "
            "personality modes: professional, playful, and pirate. I have easter eggs hidden "
            "in certain phrases. And I keep track of how many conversations I have had. Try "
            "asking me what do you see or say switch to pirate mode!"
        ),
    },
    {
        "name": "greeting",
        "keywords": ["how are you doing", "how are you today", "how you doing",
                     "what's up", "whats up", "good morning", "good afternoon"],
        "answer": (
            "I am doing great, thank you for asking! I am always happy to chat. "
            "What would you like to know about me or my project?"
        ),
    },
    {
        "name": "thanks",
        "keywords": ["thank you", "thanks", "appreciate", "cool", "awesome",
                     "nice", "good job", "well done"],
        "answer": (
            "Thank you! I am glad I could help. If you have any more questions about "
            "my hardware, my AI models, or the project, feel free to ask!"
        ),
    },
]


def check_demo_answer(text):
    """Check if text matches any demo answer keywords. Returns answer or None."""
    lower = text.lower()
    for entry in DEMO_ANSWERS:
        for keyword in entry["keywords"]:
            if keyword in lower:
                return entry["answer"], entry["name"]
    return None, None


# ============================================================
#  IMPORTS - Project Modules
# ============================================================

sys.path.insert(0, os.path.expanduser("~/echo-iris/software"))
from sound_manager import SoundManager
from scoreboard import Scoreboard
from personality_manager import PersonalityManager
from chat_memory import ChatMemory
from easter_eggs import check_easter_eggs

# Optional: RAG (intentionally disabled)
try:
    from iris_rag import query_rag
    RAG_AVAILABLE = True
except ImportError:
    RAG_AVAILABLE = False
    print("[INIT] iris_rag not available, RAG disabled")

# ============================================================
#  GLOBALS
# ============================================================

running = True
arecord_proc = None
sound_mgr = None
scoreboard = None
personality = None
memory = None
detector = None
DEBUG = False
question_count = 0
next_ack_at = random.randint(ACK_MIN_INTERVAL, ACK_MAX_INTERVAL)


# ============================================================
#  SIGNAL HANDLING
# ============================================================

def shutdown_handler(signum, frame):
    global running
    if not running:
        print(f"\n{C.RED}[IRIS] Force exit.{C.RESET}")
        os._exit(1)
    print(f"\n{C.YELLOW}[IRIS] Shutting down...{C.RESET}")
    running = False


signal.signal(signal.SIGINT, shutdown_handler)
signal.signal(signal.SIGTERM, shutdown_handler)


# ============================================================
#  DISPLAY HELPERS
# ============================================================

def get_width():
    """Get current terminal width dynamically."""
    return shutil.get_terminal_size((100, 24)).columns


def banner(text, char="="):
    w = get_width()
    print(f"\n{C.DIM}{char * w}{C.RESET}")
    print(f"  {C.BOLD}{text}{C.RESET}")
    print(f"{C.DIM}{char * w}{C.RESET}\n")


def separator():
    """Print a thin separator between conversation exchanges."""
    w = get_width()
    print(f"{C.DIM}{'- ' * (w // 2)}{C.RESET}")


def show_status(status):
    """Show a status indicator (Listening, Thinking, Speaking)."""
    w = get_width()
    padding = " " * (w - len(status) - 4)
    print(f"  {C.YELLOW}{status}{C.RESET}{padding}", end="\r", flush=True)


def clear_status():
    """Clear the status line."""
    w = get_width()
    print(" " * w, end="\r", flush=True)


def print_user(text):
    """Print user speech in demo-friendly format."""
    clear_status()
    w = get_width()
    safe = sanitize(text)
    prefix = "  YOU:  "
    wrapped = textwrap.fill(safe, width=w - len(prefix),
                            initial_indent=f"  {C.CYAN}{C.BOLD}YOU:{C.RESET}  ",
                            subsequent_indent=" " * len(prefix))
    print(wrapped)


def print_iris(text):
    """Print IRIS response in demo-friendly format."""
    clear_status()
    w = get_width()
    safe = sanitize(text)
    prefix = "  IRIS: "
    wrapped = textwrap.fill(safe, width=w - len(prefix),
                            initial_indent=f"  {C.GREEN}{C.BOLD}IRIS:{C.RESET} ",
                            subsequent_indent=" " * len(prefix))
    print(wrapped)
    print()  # blank line after IRIS response for readability


def debug_print(label, text):
    """Print debug information only when --debug flag is set."""
    if not DEBUG:
        return
    w = get_width()
    safe = sanitize(text)
    prefix = f"  {label}: "
    wrapped = textwrap.fill(safe, width=w - len(prefix),
                            initial_indent=f"  {C.DIM}{label}: ",
                            subsequent_indent=" " * len(prefix))
    print(f"{wrapped}{C.RESET}")


def print_error(text):
    """Print error message visibly."""
    clear_status()
    w = get_width()
    safe = sanitize(text)
    prefix = "  IRIS: "
    wrapped = textwrap.fill(safe, width=w - len(prefix),
                            initial_indent=f"  {C.RED}{C.BOLD}IRIS:{C.RESET} ",
                            subsequent_indent=" " * len(prefix))
    print(wrapped)
    print()
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

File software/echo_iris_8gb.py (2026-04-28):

import os
import json
import pyaudio
import requests
import subprocess
import datetime
import time
import signal
import sys
import random
import textwrap

os.environ["PYTHONUNBUFFERED"] = "1"

# ============================================================
#  ECHO IRIS v3.2 -- 8GB Edition with RAG
#  Project: ECE 202 | Team: Marc, Obaid, Giovanni
#  Colorado State University | Spring 2026
#
#  Optimized for Raspberry Pi 5 (8GB RAM)
#  DEMO_MODE = True  | RAG enabled | Small Vosk model
#  Upgrade path: see echo_iris_16gb.py for larger model
#
#  Answer flow:
#    1. Keyword match  → instant scripted answer
#    2. RAG lookup     → nomic-embed-text + qwen3.5:0.8b
#    3. Low confidence → redirect phrase
# ============================================================

# --- DYNAMIC PATHS (works on any machine) ---
HOME            = os.path.expanduser("~")
VOSK_MODEL_PATH = os.path.join(HOME, "model")
PIPER_PATH      = os.path.join(HOME, "iris_voice", "piper", "piper")
PIPER_MODEL     = os.path.join(HOME, "iris_voice", "en_GB-vctk-medium.onnx")
CHAT_LOG_FILE   = os.path.join(HOME, "iris_chat_log.txt")

# --- AUTO-DETECT USB AUDIO DEVICE ---
def find_usb_audio():
    """Auto-detect USB mic and USB speaker separately."""
    p = pyaudio.PyAudio()
    mic_index = None
    mic_name = ""
    spk_hw = "0"
    spk_name = ""
    for i in range(p.get_device_count()):
        d = p.get_device_info_by_index(i)
        name = d["name"].lower()
        if "usb" not in name:
            continue
        if "composite" in name and d["maxInputChannels"] > 0:
            mic_index = i
            mic_name = d["name"]
        elif "pnp" in name:
            if d["maxInputChannels"] > 0 and mic_index is None:
                mic_index = i
                mic_name = d["name"]
            hw = "0"
            if "hw:" in d["name"]:
                hw = d["name"].split("hw:")[1].split(",")[0]
            spk_hw = hw
            spk_name = d["name"]
    if mic_index is None:
        for i in range(p.get_device_count()):
            d = p.get_device_info_by_index(i)
            if "usb" in d["name"].lower() and d["maxInputChannels"] > 0:
                mic_index = i
                mic_name = d["name"]
                break
    if mic_index is None:
        mic_index = 0
    print(f"  Mic: index={mic_index} ({mic_name})")
    print(f"  Speaker: hw={spk_hw} ({spk_name})")
    p.terminate()
    return mic_index, spk_hw
MIC_DEVICE_INDEX, USB_HW_NUM = find_usb_audio()

# --- CONFIGURATION ---
OLLAMA_URL           = "http://localhost:11434/api/chat"
MODEL_NAME           = "qwen3:0.6b"
PIPER_SPEAKER        = 2
MAX_TOKENS           = 60
TERM_WIDTH           = 115
LISTEN_TIMEOUT       = 12
SILENCE_TIMEOUT      = 3.0
OLLAMA_TIMEOUT       = 30
MIN_WORDS_FOR_ANSWER = 2
RAG_ENABLED          = True
WAKE_WORDS = ["hello", "hey", "iris", "hello iris", "hey iris",
              "hi", "high", "aris", "virus", "hi iris"]

# --- RAG SETUP ---
rag = None

def init_rag():
    """Initialize RAG module. Fails silently if unavailable."""
    global rag
    try:
        from iris_rag import IRISRag
        rag = IRISRag()
        rag.load()
        print("  RAG: Ready")
    except Exception as e:
        print(f"  RAG: Disabled ({e})")
        rag = None

# Track recently used acks to avoid repeats
recent_acks     = []
MAX_RECENT_ACKS = 4

REPEAT_PHRASES = [
    "Sorry, I did not catch that. Could you say that again?",
    "I missed that. Can you repeat your question?",
    "Could you say that one more time?",
]

REDIRECT_PHRASES = [
    "I am not sure about that one. Try asking me about my goals, my hardware, my AI models, or what I can do!",
    "That is a bit outside my expertise. Ask me about the ECE 202 project, my creators, or my capabilities!",
    "Hmm, I do not have an answer for that. I know a lot about my hardware, my AI models, and what I can do though!",
]

DEFAULT_ACKS = [
    "Sure thing!", "Great question!", "Let me think.", "Good one!",
    "On it!", "Interesting!", "Let me check.", "One moment!",
    "Glad you asked!", "Alright!", "Let me tell you!",
]

GREETING = (
    "Hello, nice to meet you! My name is IRIS, it stands for "
    "Intelligent Raspberry-Pi Imaging System. What would you like to know?"
)
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

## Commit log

2026-04-28 Add v1.0 finalization batch 2: CONTRIBUTING, BOM, platform specs, gitignore exclusions
2026-04-28 v1.0 finalization batch 5: /3d-models/ lid and cage STLs
    [IRIS_Cage_Base.stl, IRIS_Lid_Cover.stl]
2026-04-28 Add production software for 16GB build (PR #5)
    Adds /software/ directory with echo_iris_16gb.py production runtime, 5 helper modules (sound_manager, scoreboard, personality_manager, chat_memory, easter_eggs), iris_detector for IMX500 object detection, iris_monitor, iris_rag, iris_knowledge.md RAG corpus, run.sh launcher, sound effects library, and 8GB build script. Includes Vosk mishearing patches (parrot to pirate, posts to plus) and sound_manager docstring fix. Also adds requirements_snapshot.txt capturing the Pi environment as it ran on demo day, and updates .gitignore for runtime state files and backups.
    [chat_memory.py, easter_eggs.py, echo_iris_16gb.py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]
